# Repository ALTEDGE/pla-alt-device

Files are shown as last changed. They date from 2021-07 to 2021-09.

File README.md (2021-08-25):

# pla-alt-device

This repository contains the source code and hardware design files for the PLA ALT Avatar Motion Controller.

To compile the source code, use the [Arduino IDE](https://www.arduino.cc/en/software). After running the Arduino IDE, an `Arduino` folder is created in your Documents folder. Copy the `hardware` folder in this repo into that `Arudino` folder; then, the Arduino IDE should show "PLA ALT" as a board option.

The controller's hardware was designed using [EAGLE](https://www.autodesk.com/products/eagle/overview). Schematic and board files are located in the `eagle` folder.

## Brief user guide

The controller appears to the computer as a regular gaming joystick/controller. The [PLA ALT GUI](https://github.com/ALTEDGE/pla-alt-gui) must be running in order to use the controller to its full potential.

To reprogram the ALT controller, put it into programming mode by holding down the right joystick button while plugging into the computer; the LEDs should not turn on. After uploading new code through the IDE, reconnect the controller.

The ALT controller self-calibrates when it is first powered on. If recalibration is ever necessary, hold down the left joystick button while plugging into the computer. Release the button once the LEDs light up white. Calibration is finished once the LEDs return to blue.

### Licensing

The ALT controller's source code is licensed under the GNU GPLv3; see the LICENSE file in the top directory. The controller's hardware files (EAGLE schematic and board files) are licensed under the TAPR Open Hardware License; see the LICENSE file in the `eagle` folder.

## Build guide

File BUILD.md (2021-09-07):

# Programming the PLA ALT controller

This guide will show you how to program the PLA ALT controller with new firmware. This includes burning the PLA ALT bootloader and uploading the latest code.

To burn the bootloader, two pieces of hardware are required:

1. A USBasp programmer (available from many places, like [Amazon](https://www.amazon.com/Geekstory-Microcontroller-Programmer-Downloader-Adapter/dp/B07NZ59VK2/)).
2. A 6-pin Pogo adapter ([on Amazon](https://www.amazon.com/pin-AVR-ICSP-Pogo-Adapter/dp/B075Q25BK3/)).

This guide assumes you are running Windows 10.

## 1. Prepare the USB programmer

Plug the USB programmer into the computer. Then, download and run the program Zadig from [here](https://zadig.akeo.ie/). This program installs drivers for the programmer.

Once open, the drop-down box should contain an entry (like "USBasp"). Click "Install Driver"; once finished, exit Zadig.

## 2. Prepare the Arduino IDE

The Arduino IDE can be downloaded [here](https://www.arduino.cc/en/software). Once installed, run the Arduino IDE program. This will create a folder that we will be copying files into. Just close the IDE once it is open.

## 3. Download the PLA ALT source code

Download a .zip of the latest source code [here](https://github.com/ALTEDGE/pla-alt-device/archive/refs/heads/master.zip). Once downloaded, unzip the archive. Rename the extracted folder to `pla-device`.

Inside the `pla-device` folder is a `hardware` folder. Copy and paste the `hardware` folder into `Documents\Arduino`.

## 4. Programming the PLA ALT controller

Now, open the Arduino IDE again. From the menu bar, select **Tools > Board: > PLA: > PLA ALT**. Also select **Tools > Programmer: > USBasp**.

### a. Burning the bootloader

Plug the PLA controller into the computer, and connect the programmer to it by pressing it into the programming port on the bottom of the PLA controller (check the pin labels and make sure they line up and match):

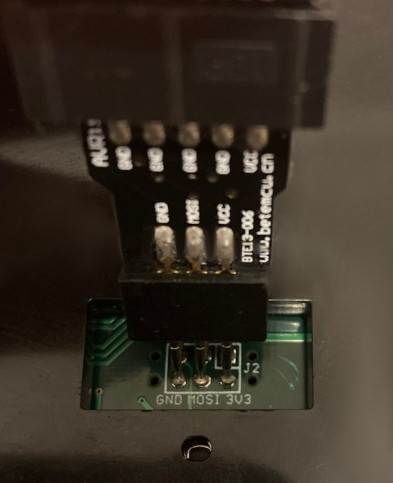
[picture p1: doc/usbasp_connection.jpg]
Programmer connection


Keep the programmer connected, and choose **Tools > Burn Bootloader** from the menu bar. Once the bootloader burning is finished, you may remove the programmer from the PLA controller.

### b. Uploading the code

Under **Tools > Port**, we need to select the COM port for the PLA controller. If there are multiple COM ports, open Device Manager (can be found by pressing Windows key + X) and look under "Ports (COM & LPT)". The PLA controller will appear as a Sparkfun Pro Micro.

Once the port is selected, simply press **Sketch > Upload**. When finished, reconnect the controller and the blue/white LEDs should light up.

## Notes

* Once the bootloader has been burned to a device, it does not need to be burned again (unless there is a new bootloader version).
* To program the PLA controller after the bootloader has been uploaded, plug the contoller into the computer **while** pressing down the right joystick. The controller's lights will not turn on if you successfully entered the programming mode.
* If an error occurs while working with the Arduino IDE, go to **File > Prefences** and next to "Show verbose output during:" check both the compilation and upload boxes. Repeat the step you were stuck on, and detailed information on what went wrong should be given.

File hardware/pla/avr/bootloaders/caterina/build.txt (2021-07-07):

make clean
make PID=0x9209 F_CPU=16000000
copy Caterina.hex Caterina-wiflyin.hex
make clean
make PID=0x9207 F_CPU=8000000
copy Caterina.hex Caterina-lilypadusb.hex
make clean
make PID=0x9205 F_CPU=16000000
copy Caterina.hex Caterina-promicro16.hex
make clean
make PID=0x9203 F_CPU=8000000
copy Caterina.hex Caterina-promicro8.hex 
make clean
make PID=0x2B74 F_CPU=16000000
copy Caterina.hex Caterina-makey.hex
make clean
make PID=0xF100 F_CPU=8000000
copy Caterina.hex Caterina-fio.hex
make clean
make PID=0x920B F_CPU=16000000
copy Caterina.hex Caterina-minibench.hex
make clean
make PID=0x0110 F_CPU=8000000
copy Caterina.hex Caterina-lilypadusbplus.hex

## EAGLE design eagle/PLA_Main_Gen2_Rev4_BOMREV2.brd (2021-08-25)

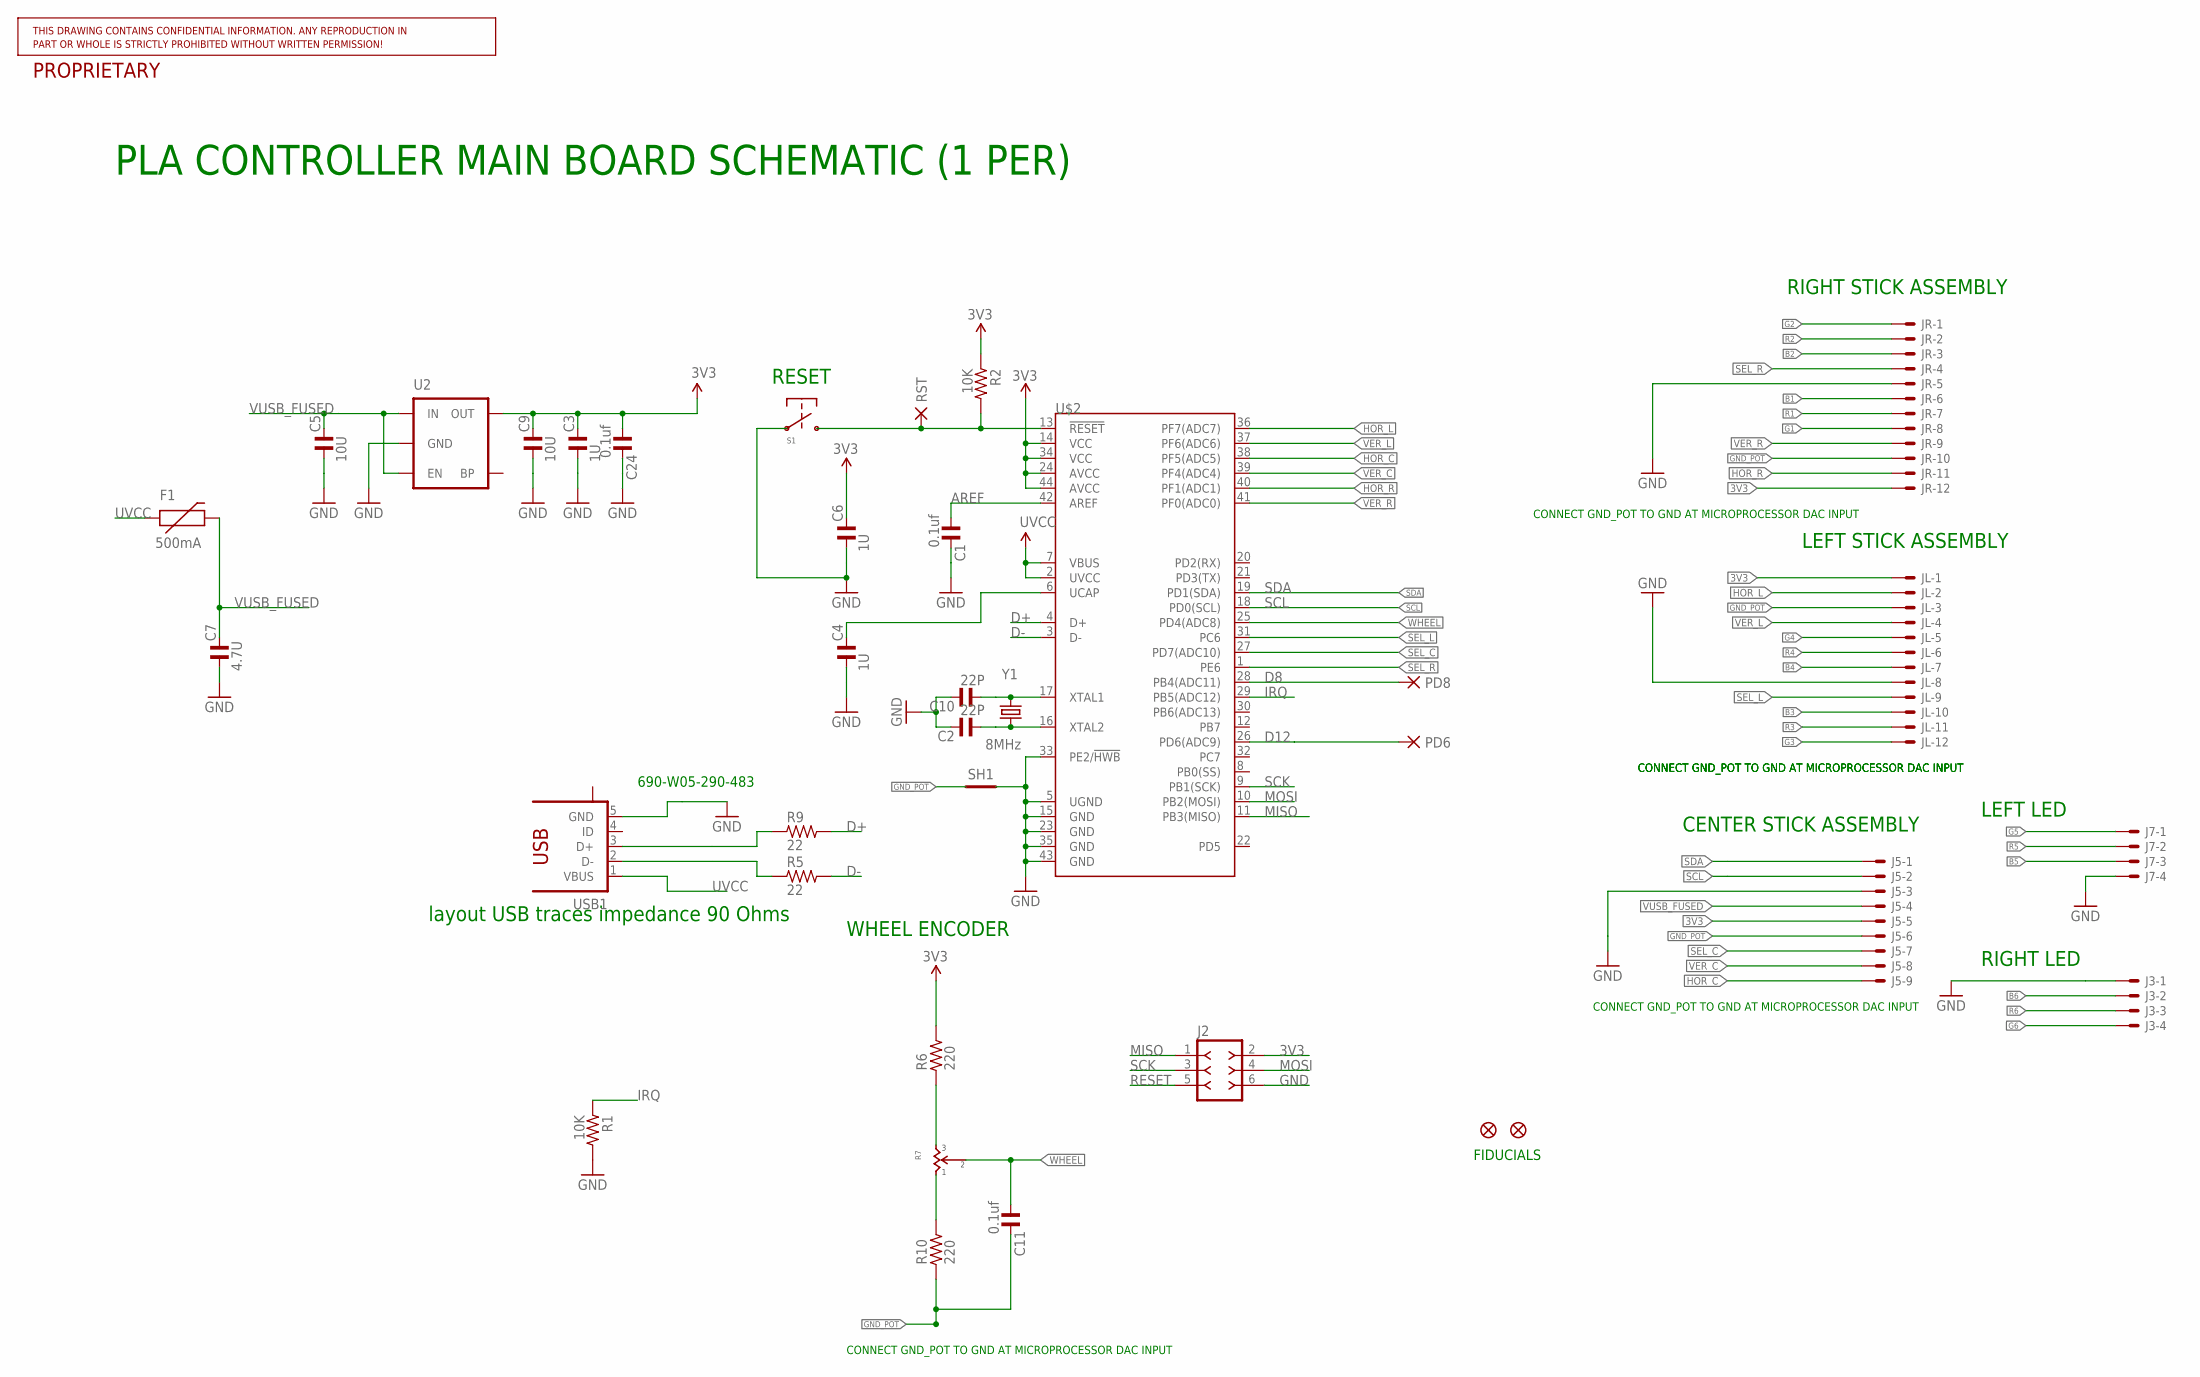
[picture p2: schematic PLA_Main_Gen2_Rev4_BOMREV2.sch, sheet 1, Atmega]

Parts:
C1, C11, C24: 0.1uf; C0603; PARTNO 64K2839
C2, C10: 22P; C0603; PARTNO 06035C220JAT2A
C3, C4, C6: 1U; C0603; PARTNO CL10B105KP8NNNC
C5, C9: 10U; C1206; PARTNO C3216X5R1H106K160AB
C7: 4.7U; C0603; PARTNO GRM188R61A475KE15D
F1: 500mA; PTC-1206; PARTNO NANOSMDH075F-02
J2: F-2X03-DIL-100; DIL-100-2X03; PARTNO *
J3, J7: SM04B-SRSS-TB; PARTNO SM04B-SRSS-TB(LF)(SN)
J5: SM09B-SRSS-TB; PARTNO SM09B-SRSS-TB
JL: SM12B-SRSS-TB; PARTNO SM12B-SRSS-TB(LF)(SN)
JP1, JP2: FIDUCIALUFIDUCIAL; MICRO-FIDUCIAL; PARTNO *
JR: SM12B-SRSS-TB; PARTNO SM12B-SRSS-TB(LF)(SN)
PD6, PD8: PAD-SMD12R; SMD12R
R1, R2: 10K; R0603; PARTNO ERJ-PA3J103V
R5, R9: 22; R0603; PARTNO ERJ-PA3J220V
R6, R10: 220; R0603; PARTNO ERJ-PA3J221V
R7: SV01A103AEA01R00; PARTNO SV01A103AEA01R00
RST: PAD-SMD10R; SMD10R
S1: KMR211GLFS; PARTNO KMR211GLFS
SH1: SHORTT5; SHORT_TOP-50; PARTNO *
U2: V_REG_LDOSMD; SOT23-5; PARTNO MIC5219-3.3YM5-TR
U$2: ATMEGA32U4QFN; QFN-44; PARTNO ATMEGA32U4-MU
USB1: 10118192-0001LF; PARTNO 10118192-0001LF
Y1: 8MHz; CRYSTAL-SMD-5X3; PARTNO ABM3B-8.000MHZ-B2-T

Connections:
3V3: C3.2, C6.2, C9.2, C24.1, J2.2, J5.5, JL.1, JR.12, R2.1, R6.2, U2.5 (OUT), U$2.14 (VCC), U$2.24 (AVCC), U$2.34 (VCC), U$2.44 (AVCC); also elsewhere on the board
AREF: C1.1, U$2.42 (AREF)
B1: JR.6; also elsewhere on the board
B2: JR.3; also elsewhere on the board
B3: JL.10; also elsewhere on the board
B4: JL.7; also elsewhere on the board
B5: J7.3; also elsewhere on the board
B6: J3.2; also elsewhere on the board
D8: PD8.PAD, U$2.28 (PB4(ADC11))
D12: PD6.PAD, U$2.26 (PD6(ADC9))
D+: R9.2, U$2.4 (D+)
D-: R5.2, U$2.3 (D-)
G1: JR.8; also elsewhere on the board
G2: JR.1; also elsewhere on the board
G3: JL.12; also elsewhere on the board
G4: JL.5; also elsewhere on the board
G5: J7.1; also elsewhere on the board
G6: J3.4; also elsewhere on the board
GND: C1.2, C2.2, C3.1, C4.1, C5.1, C6.1, C7.1, C9.1, C10.2, C24.2, J2.6, J3.1, J5.3, J7.4, JL.8, JR.5, R1.2, S1.1A (1), S1.1B (1), SH1.2, U2.2 (GND), U$2.5 (UGND), U$2.15 (GND), U$2.23 (GND), U$2.33 (PE2/!HWB), U$2.35 (GND), U$2.43 (GND), USB1.5 (GND); also elsewhere on the board
GND_POT: C11.2, J5.6, JL.3, JR.10, R10.1, SH1.1
HOR_C: J5.9, U$2.38 (PF5(ADC5))
HOR_L: JL.2, U$2.36 (PF7(ADC7))
HOR_R: JR.11, U$2.40 (PF1(ADC1))
IRQ: R1.1, U$2.29 (PB5(ADC12))
MISO: J2.1, U$2.11 (PB3(MISO))
MOSI: J2.4, U$2.10 (PB2(MOSI))
unnamed: C2.1, U$2.16 (XTAL2), Y1.1
unnamed: C10.1, U$2.17 (XTAL1), Y1.3 (2)
unnamed: C4.2, U$2.6 (UCAP)
unnamed: R6.1, R7.3
unnamed: R7.1, R10.2
R1: JR.7; also elsewhere on the board
R2: JR.2; also elsewhere on the board
R3: JL.11; also elsewhere on the board
R4: JL.6; also elsewhere on the board
R5: J7.2; also elsewhere on the board
R6: J3.3; also elsewhere on the board
RESET: J2.5, R2.2, RST.PAD, S1.2A (2), S1.2B (2), U$2.13 (!RESET)
SCK: J2.3, U$2.9 (PB1(SCK))
SCL: J5.2, U$2.18 (PD0(SCL)); also elsewhere on the board
SDA: J5.1, U$2.19 (PD1(SDA)); also elsewhere on the board
SEL_C: J5.7, U$2.27 (PD7(ADC10))
SEL_L: JL.9, U$2.31 (PC6)
SEL_R: JR.4, U$2.1 (PE6)
USB_N: R5.1, USB1.2 (D-)
USB_P: R9.1, USB1.3 (D+)
UVCC: F1.1, U$2.2 (UVCC), U$2.7 (VBUS), USB1.1 (VBUS)
VER_C: J5.8, U$2.39 (PF4(ADC4))
VER_L: JL.4, U$2.37 (PF6(ADC6))
VER_R: JR.9, U$2.41 (PF0(ADC0))
VUSB_FUSED: C5.2, C7.2, F1.2, J5.4, U2.1 (IN), U2.3 (EN); also elsewhere on the board
WHEEL: C11.1, R7.2, R7.2A (2), U$2.25 (PD4(ADC8))

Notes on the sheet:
690-W05-290-483
layout USB traces impedance 90 Ohms
LEFT STICK ASSEMBLY
CONNECT GND_POT TO GND AT MICROPROCESSOR DAC INPUT
RIGHT STICK ASSEMBLY
CENTER STICK ASSEMBLY
WHEEL ENCODER
RESET
LEFT LED
RIGHT LED
FIDUCIALS
PLA CONTROLLER MAIN BOARD SCHEMATIC (1 PER)

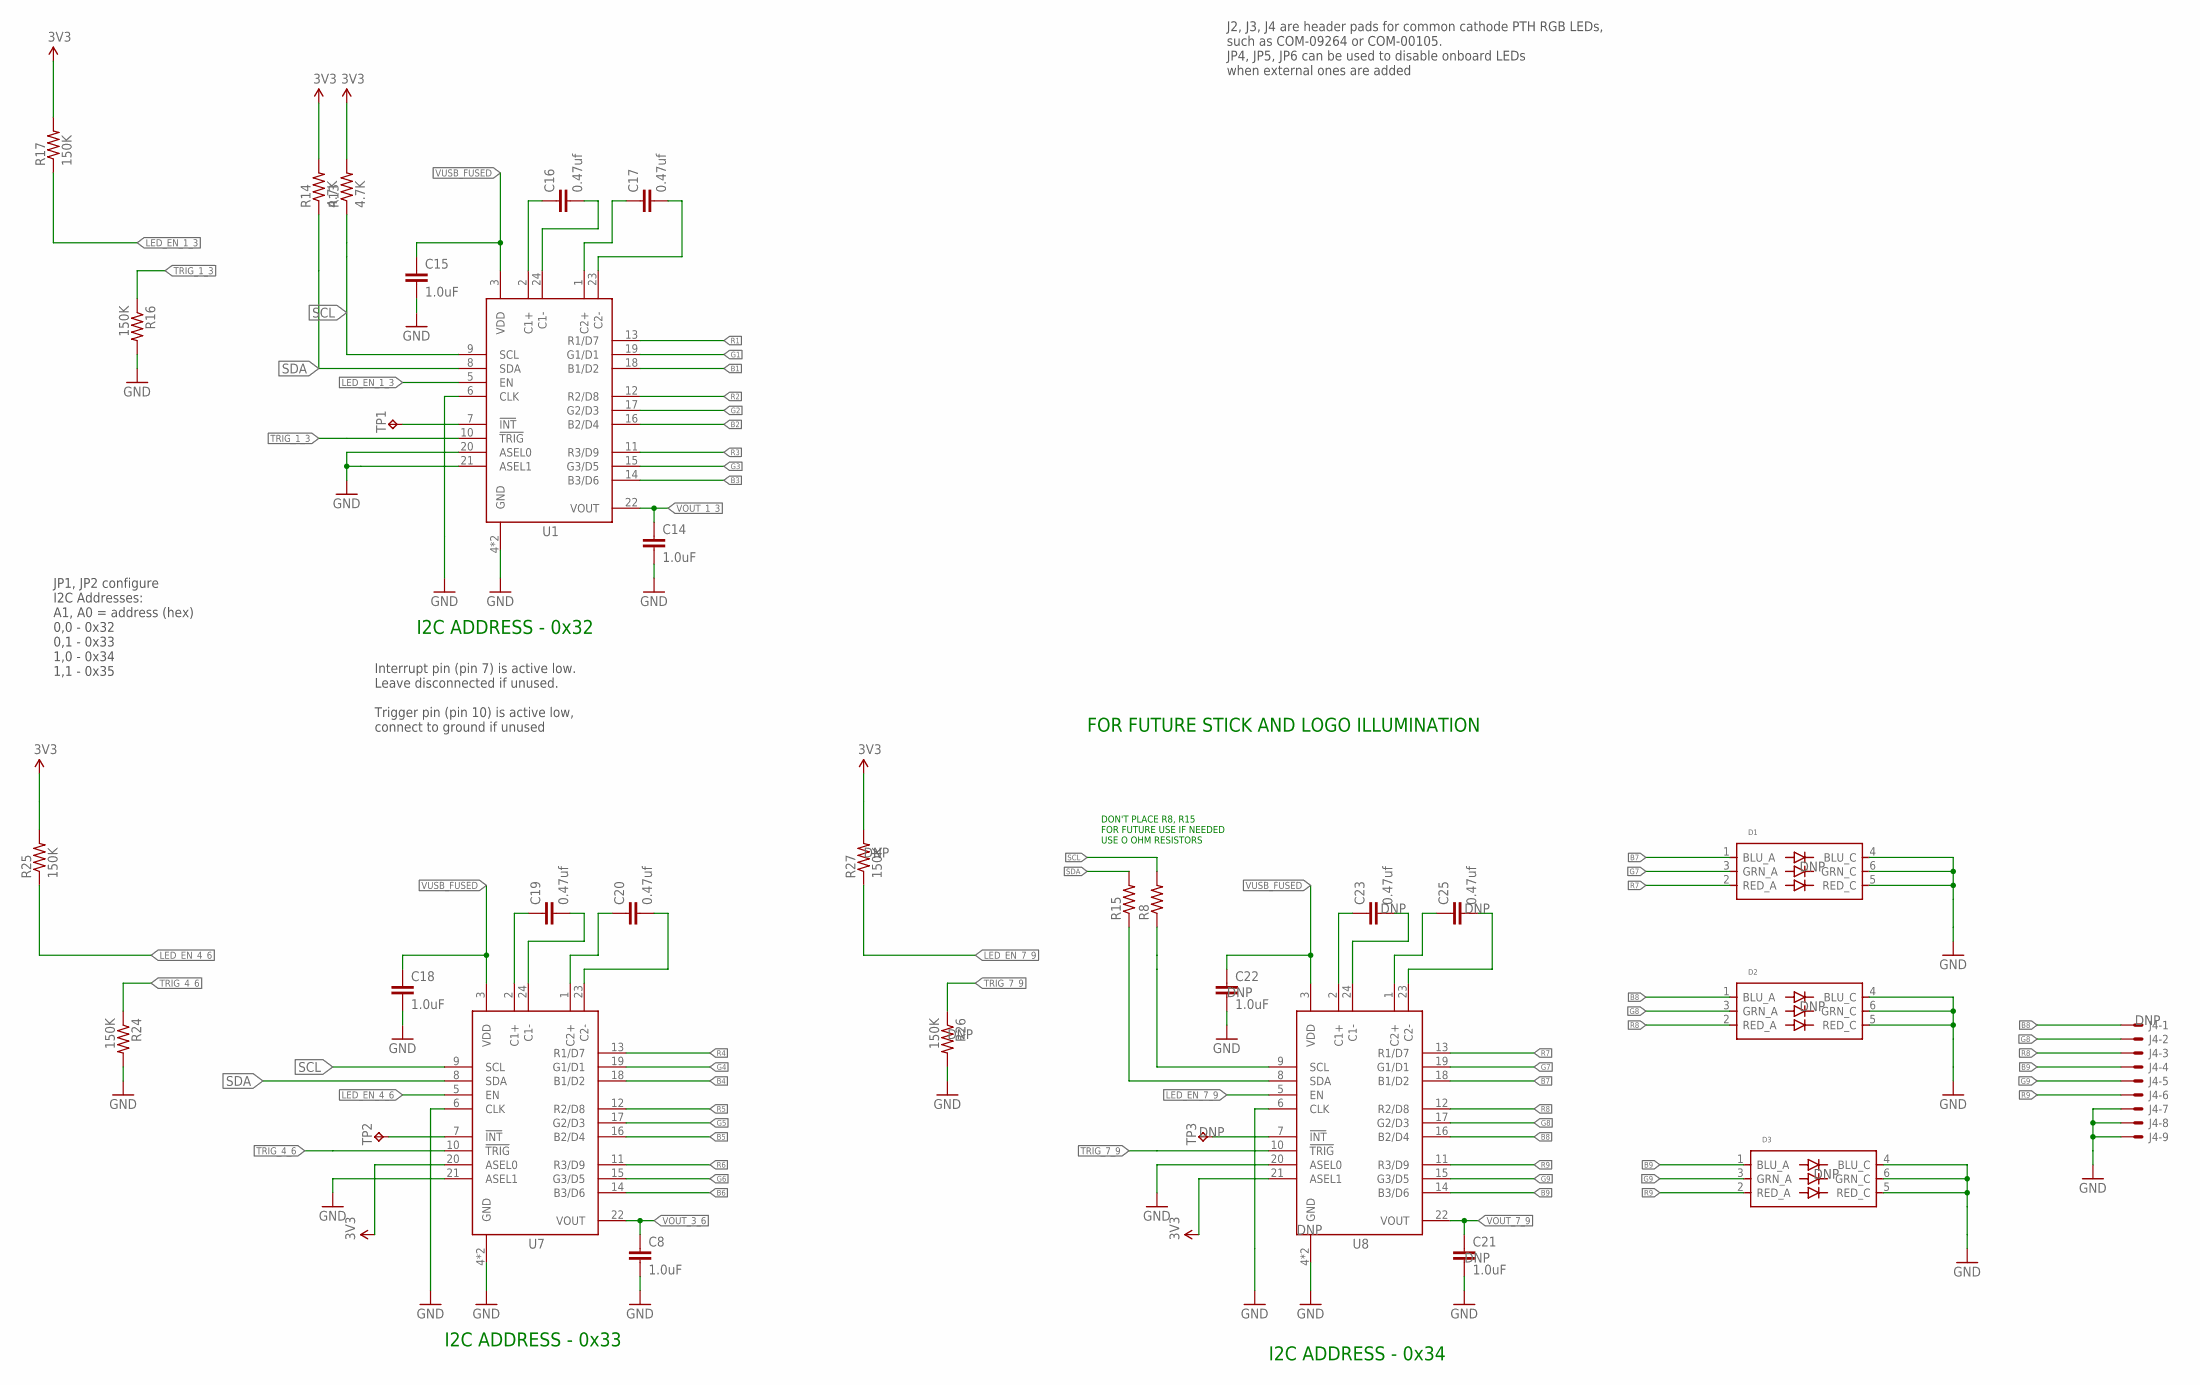
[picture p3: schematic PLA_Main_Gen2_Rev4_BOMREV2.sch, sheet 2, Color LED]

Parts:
C8, C14, C15, C18, C21, C22: 1.0uF; 0603-CAP; PARTNO CL10B105KP8NNNC
C16, C17, C19, C20, C23, C25: 0.47uf; 0603-CAP; PARTNO 0603YG474ZAT2A
D1, D2, D3: XZFBBM2ACRDG92W-3; PARTNO XZFBBM2ACRDG92W-3
J4: BM09B-SRSS-TB; PARTNO BM09B-SRSS-TB
R8, R15: 4.7KOHM-1/10W-1%(0603); 0603-RES; PARTNO ERJ-PA3J472V
R13, R14: 4.7K; 0603-RES; PARTNO ERJ-PA3J472V
R16, R17, R24, R25, R26, R27: 150K; 0603-RES; PARTNO ERJ-PA3J154V
TP1, TP2, TP3: TP-040; PARTNO *
U1, U7, U8: LP55231WQFN; WQFN-24; PARTNO LP55231SQX/NOPB

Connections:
3V3: R13.2, R14.2, R17.2, R25.2, R27.2, U7.20 (ASEL0), U8.21 (ASEL1); also elsewhere on the board
B1: U1.18 (B1/D2); also elsewhere on the board
B2: U1.16 (B2/D4); also elsewhere on the board
B3: U1.14 (B3/D6); also elsewhere on the board
B4: U7.18 (B1/D2); also elsewhere on the board
B5: U7.16 (B2/D4); also elsewhere on the board
B6: U7.14 (B3/D6); also elsewhere on the board
B7: D1.1 (BLU_A), U8.18 (B1/D2)
B8: D2.1 (BLU_A), J4.1, U8.16 (B2/D4)
B9: D3.1 (BLU_A), J4.4, U8.14 (B3/D6)
G1: U1.19 (G1/D1); also elsewhere on the board
G2: U1.17 (G2/D3); also elsewhere on the board
G3: U1.15 (G3/D5); also elsewhere on the board
G4: U7.19 (G1/D1); also elsewhere on the board
G5: U7.17 (G2/D3); also elsewhere on the board
G6: U7.15 (G3/D5); also elsewhere on the board
G7: D1.3 (GRN_A), U8.19 (G1/D1)
G8: D2.3 (GRN_A), J4.2, U8.17 (G2/D3)
G9: D3.3 (GRN_A), J4.5, U8.15 (G3/D5)
GND: C8.2, C14.2, C15.2, C18.2, C21.2, C22.2, D1.4 (BLU_C), D1.5 (RED_C), D1.6 (GRN_C), D2.4 (BLU_C), D2.5 (RED_C), D2.6 (GRN_C), D3.4 (BLU_C), D3.5 (RED_C), D3.6 (GRN_C), J4.7, J4.8, J4.9, R16.2, R24.2, R26.2, U1.4 (GND), U1.6 (CLK), U1.20 (ASEL0), U1.21 (ASEL1), U1.EP (GND), U7.4 (GND), U7.6 (CLK), U7.21 (ASEL1), U7.EP (GND), U8.4 (GND), U8.6 (CLK), U8.20 (ASEL0), U8.EP (GND); also elsewhere on the board
LED_EN_1_3: R17.1, U1.5 (EN)
LED_EN_4_6: R25.1, U7.5 (EN)
LED_EN_7_9: R27.1, U8.5 (EN)
unnamed: TP1.1, U1.7 (!INT)
unnamed: C19.1, U7.2 (C1+)
unnamed: C19.2, U7.24 (C1-)
unnamed: C16.1, U1.2 (C1+)
unnamed: C16.2, U1.24 (C1-)
unnamed: C17.1, U1.1 (C2+)
unnamed: C17.2, U1.23 (C2-)
unnamed: C20.1, U7.1 (C2+)
unnamed: C20.2, U7.23 (C2-)
unnamed: TP2.1, U7.7 (!INT)
unnamed: C23.1, U8.2 (C1+)
unnamed: C23.2, U8.24 (C1-)
unnamed: C25.1, U8.1 (C2+)
unnamed: C25.2, U8.23 (C2-)
unnamed: TP3.1, U8.7 (!INT)
R1: U1.13 (R1/D7); also elsewhere on the board
R2: U1.12 (R2/D8); also elsewhere on the board
R3: U1.11 (R3/D9); also elsewhere on the board
R4: U7.13 (R1/D7); also elsewhere on the board
R5: U7.12 (R2/D8); also elsewhere on the board
R6: U7.11 (R3/D9); also elsewhere on the board
R7: D1.2 (RED_A), U8.13 (R1/D7)
R8: D2.2 (RED_A), J4.3, U8.12 (R2/D8)
R9: D3.2 (RED_A), J4.6, U8.11 (R3/D9)
SCL: R8.2, R13.1, U1.9 (SCL), U7.9 (SCL); also elsewhere on the board
SCL2: R8.1, U8.9 (SCL)
SDA: R14.1, R15.2, U1.8 (SDA), U7.8 (SDA); also elsewhere on the board
SDA2: R15.1, U8.8 (SDA)
TRIG_1_3: R16.1, U1.10 (!TRIG)
TRIG_4_6: R24.1, U7.10 (!TRIG)
TRIG_7_9: R26.1, U8.10 (!TRIG)
VOUT_1_3: C14.1, U1.22 (VOUT)
VOUT_3_6: C8.1, U7.22 (VOUT)
VOUT_7_9: C21.1, U8.22 (VOUT)
VUSB_FUSED: C15.1, C18.1, C22.1, U1.3 (VDD), U7.3 (VDD), U8.3 (VDD); also elsewhere on the board

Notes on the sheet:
JP1, JP2 configure I2C Addresses: A1, A0 = address (hex) 0,0 - 0x32 0,1 - 0x33 1,0 - 0x34 1,1 - 0x35
J2, J3, J4 are header pads for common cathode PTH RGB LEDs, such as COM-09264 or COM-00105. JP4, JP5, JP6 can be used to disable onboard LEDs when external ones are added
Interrupt pin (pin 7) is active low. Leave disconnected if unused. Trigger pin (pin 10) is active low, connect to ground if unused
FOR FUTURE STICK AND LOGO ILLUMINATION
I2C ADDRESS - 0x32
I2C ADDRESS - 0x33
I2C ADDRESS - 0x34
DON'T PLACE R8, R15 FOR FUTURE USE IF NEEDED USE O OHM RESISTORS

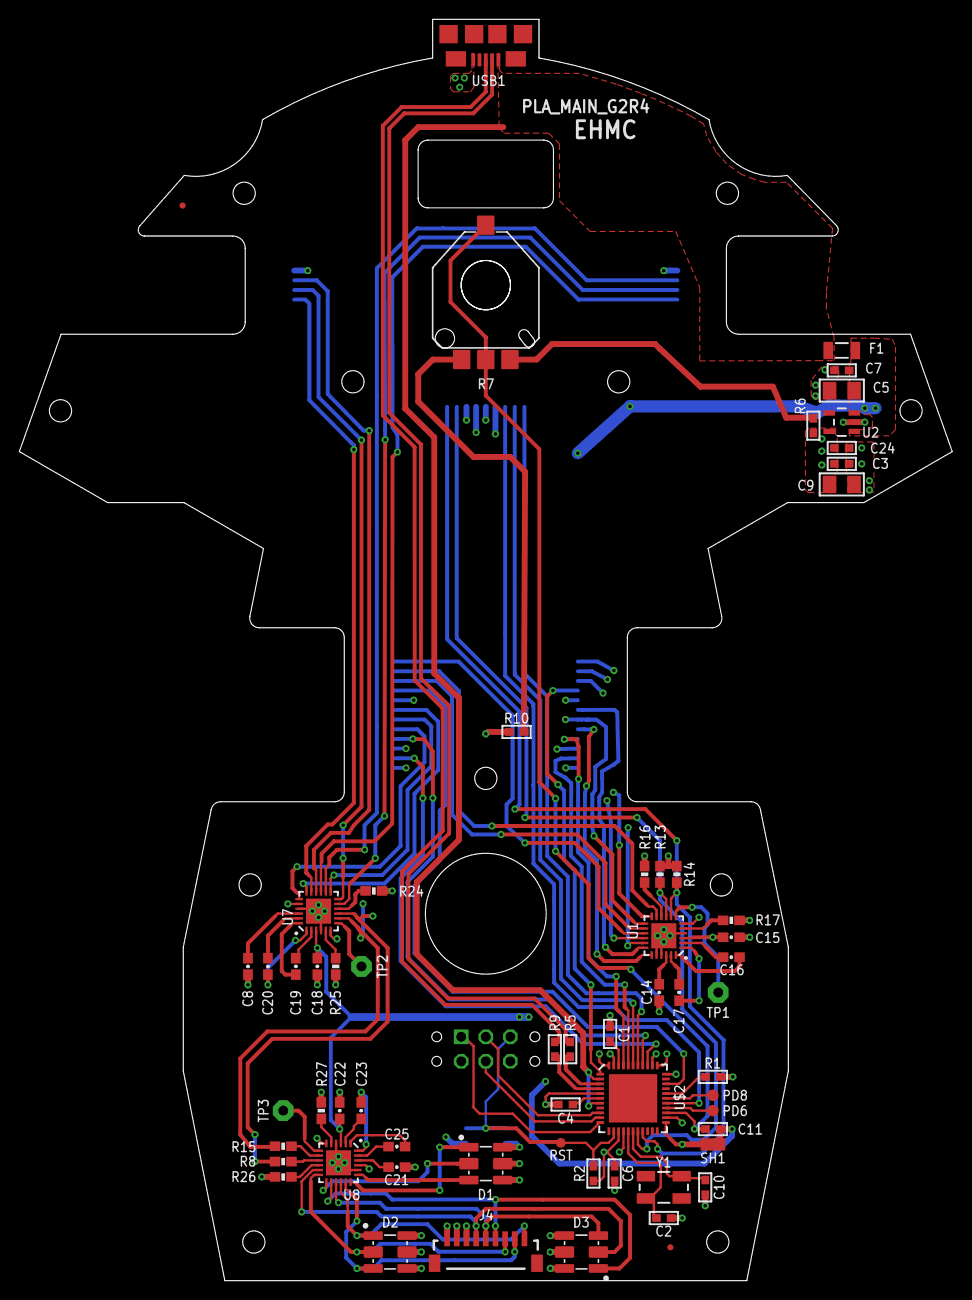
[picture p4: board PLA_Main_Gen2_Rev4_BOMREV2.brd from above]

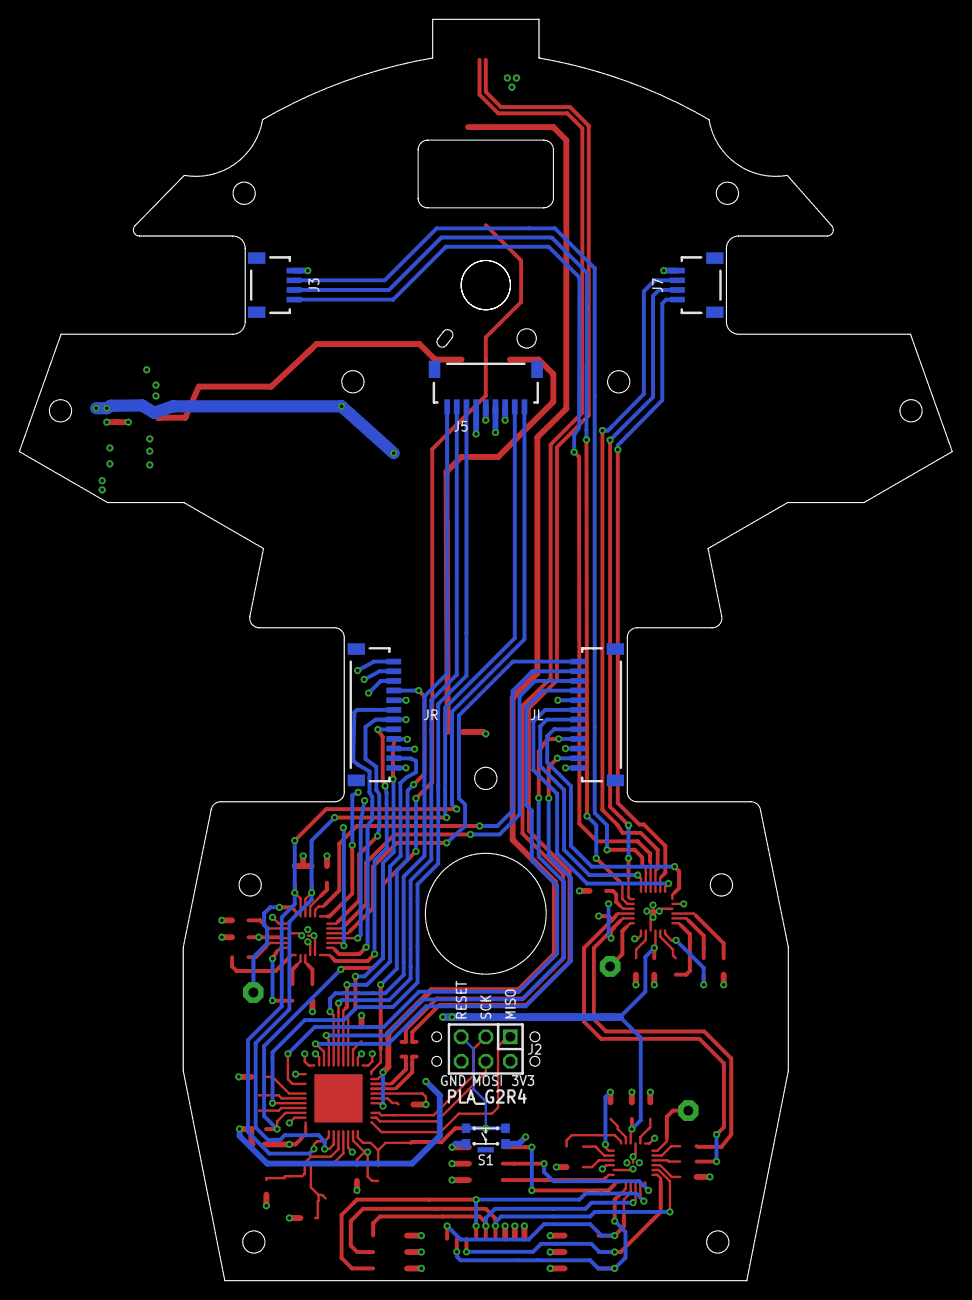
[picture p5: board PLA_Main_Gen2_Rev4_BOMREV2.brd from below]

Board: 4 copper layers, 96.5 x 130.5 mm, 70 parts (7 on the bottom side), 87 nets.

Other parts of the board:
U$3: FAB_FRAME_ANSI-A
U$4: FAB_DOCFIELD_GENERIC

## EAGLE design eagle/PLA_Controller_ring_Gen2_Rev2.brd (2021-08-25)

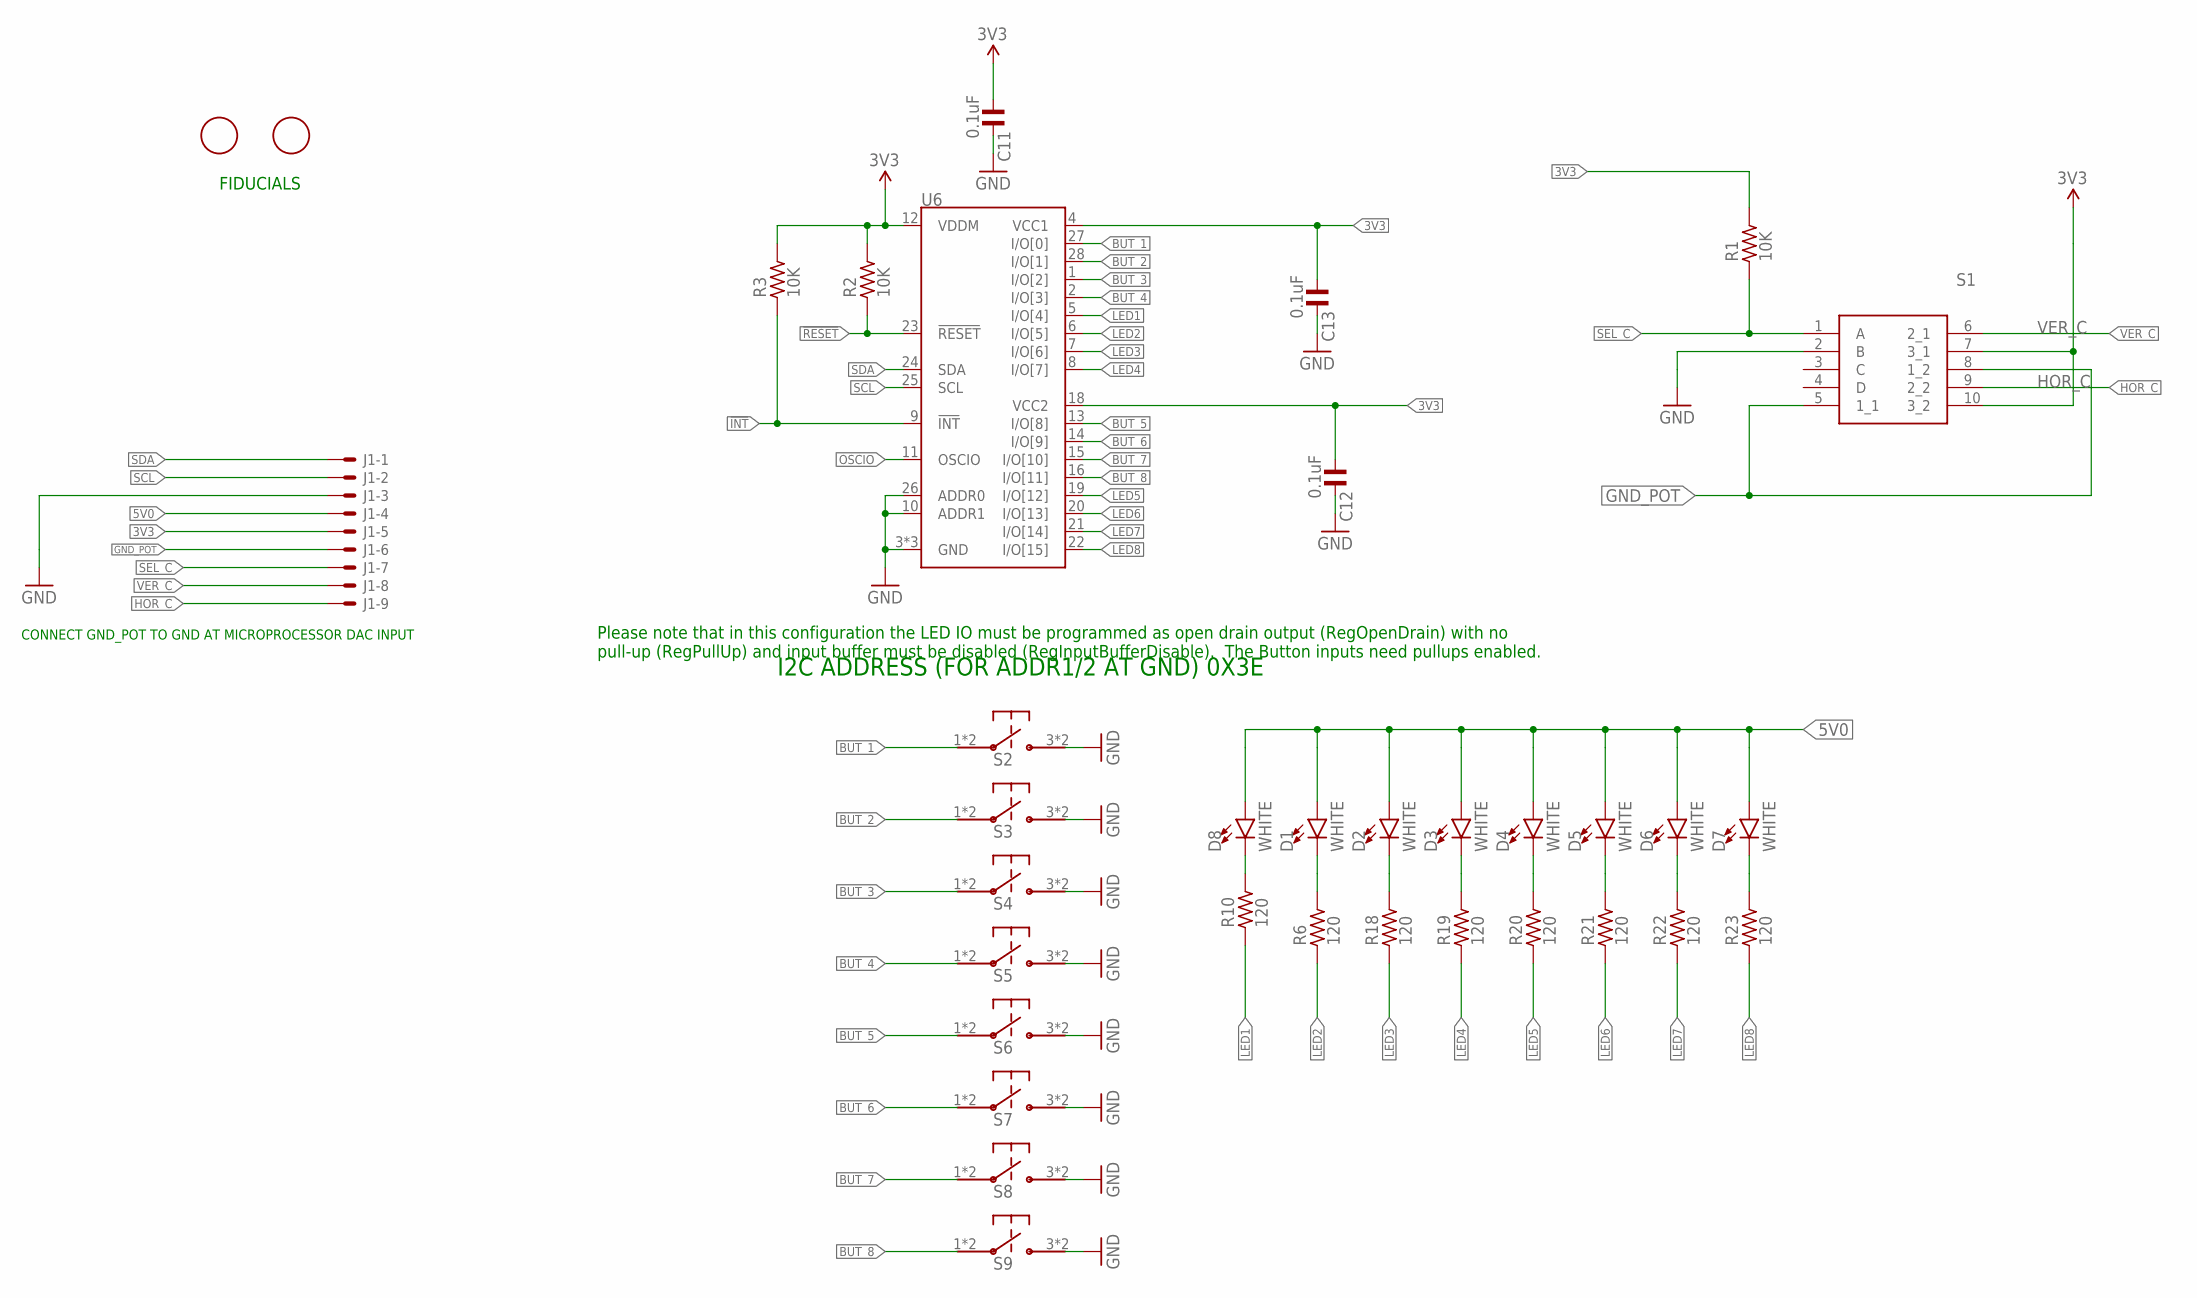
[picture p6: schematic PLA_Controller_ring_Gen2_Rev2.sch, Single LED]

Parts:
C11, C12, C13: 0.1uF; C0603; PARTNO CAP-00810
D1, D2, D3, D4, D5, D6, D7, D8: WHITE; LED-0603; PARTNO QBLP601-IW
J1: BM09B-SRSS-TB; PARTNO BM09B-SRSS-TB
R1, R2, R3: 10K; R0603; PARTNO ERJ-2GEJ103X
R6, R10, R18, R19, R20, R21, R22, R23: 120; R0603; PARTNO ERJ-PA3J121V
S1: RKJXV1224005; PARTNO RKJXV1224005
S2, S3, S4, S5, S6, S7, S8, S9: TL3315NF100Q; PARTNO TL3315NF100Q
U6: SX1509; QFN-28; PARTNO SX1509BIULTRT
U$8, U$9: FIDUCIAL; FIDUCIAL_1MM; PARTNO *

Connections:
3V3: C11.1, C12.1, C13.1, J1.5, R1.2, R2.2, R3.2, S1.7 (3_1), S1.10 (3_2), U6.4 (VCC1), U6.12 (VDDM), U6.18 (VCC2)
5V0: D1.A, D2.A, D3.A, D4.A, D5.A, D6.A, D7.A, D8.A, J1.4
!INT: R3.1, U6.9 (!INT)
!RESET: R2.1, U6.23 (!RESET)
BUT_1: S2.1, S2.2, U6.27 (I/O[0])
BUT_2: S3.1, S3.2, U6.28 (I/O[1])
BUT_3: S4.1, S4.2, U6.1 (I/O[2])
BUT_4: S5.1, S5.2, U6.2 (I/O[3])
BUT_5: S6.1, S6.2, U6.13 (I/O[8])
BUT_6: S7.1, S7.2, U6.14 (I/O[9])
BUT_7: S8.1, S8.2, U6.15 (I/O[10])
BUT_8: S9.1, S9.2, U6.16 (I/O[11])
GND: C11.2, C12.2, C13.2, J1.3, S1.2 (B), S2.3, S2.4, S3.3, S3.4, S4.3, S4.4, S5.3, S5.4, S6.3, S6.4, S7.3, S7.4, S8.3, S8.4, S9.3, S9.4, U6.3 (GND), U6.10 (ADDR1), U6.17 (GND), U6.26 (ADDR0), U6.29 (GND)
GND_POT: J1.6, S1.5 (1_1), S1.8 (1_2)
HOR_C: J1.9, S1.9 (2_2)
LED1: R10.1, U6.5 (I/O[4])
LED2: R6.1, U6.6 (I/O[5])
LED3: R18.1, U6.7 (I/O[6])
LED4: R19.1, U6.8 (I/O[7])
LED5: R20.1, U6.19 (I/O[12])
LED6: R21.1, U6.20 (I/O[13])
LED7: R22.1, U6.21 (I/O[14])
LED8: R23.1, U6.22 (I/O[15])
unnamed: D1.C, R6.2
unnamed: D8.C, R10.2
unnamed: D2.C, R18.2
unnamed: D3.C, R19.2
unnamed: D4.C, R20.2
unnamed: D5.C, R21.2
unnamed: D6.C, R22.2
unnamed: D7.C, R23.2
OSCIO: U6.11 (OSCIO)
SCL: J1.2, U6.25 (SCL)
SDA: J1.1, U6.24 (SDA)
SEL_C: J1.7, R1.1, S1.1 (A)
VER_C: J1.8, S1.6 (2_1)

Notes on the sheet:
Please note that in this configuration the LED IO must be programmed as open drain output (RegOpenDrain) with no pull-up (RegPullUp) and input buffer must be disabled (RegInputBufferDisable). The Button inputs need pullups enabled.
CONNECT GND_POT TO GND AT MICROPROCESSOR DAC INPUT
I2C ADDRESS (FOR ADDR1/2 AT GND) 0X3E
FIDUCIALS

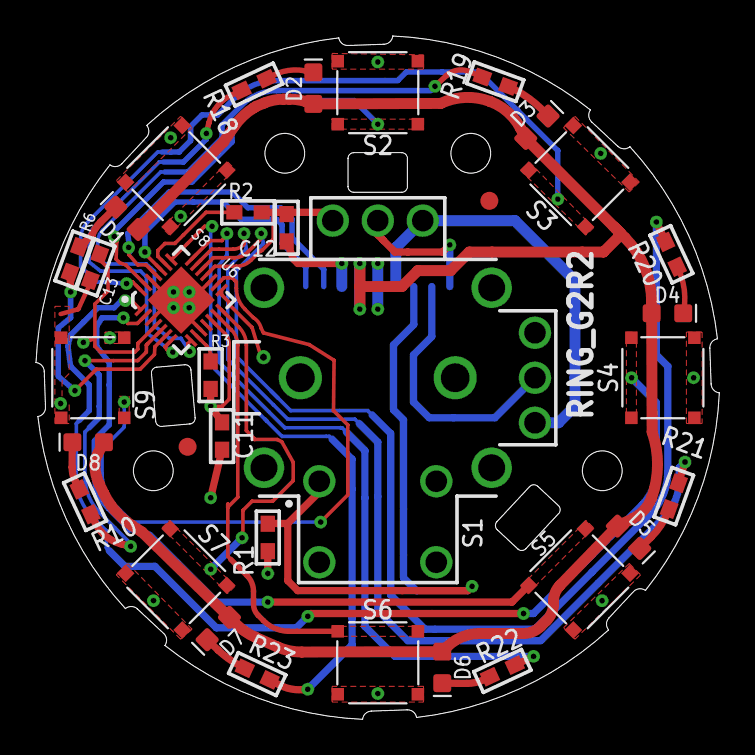
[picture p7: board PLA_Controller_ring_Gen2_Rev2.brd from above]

Board: 4 copper layers, 38.0 x 38.0 mm, 41 parts (1 on the bottom side), 35 nets.

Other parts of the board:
U$2, U$5, U$6, U$7: 086
U$3: FAB_FRAME_ANSI-A
U$4: FAB_DOCFIELD_GENERIC

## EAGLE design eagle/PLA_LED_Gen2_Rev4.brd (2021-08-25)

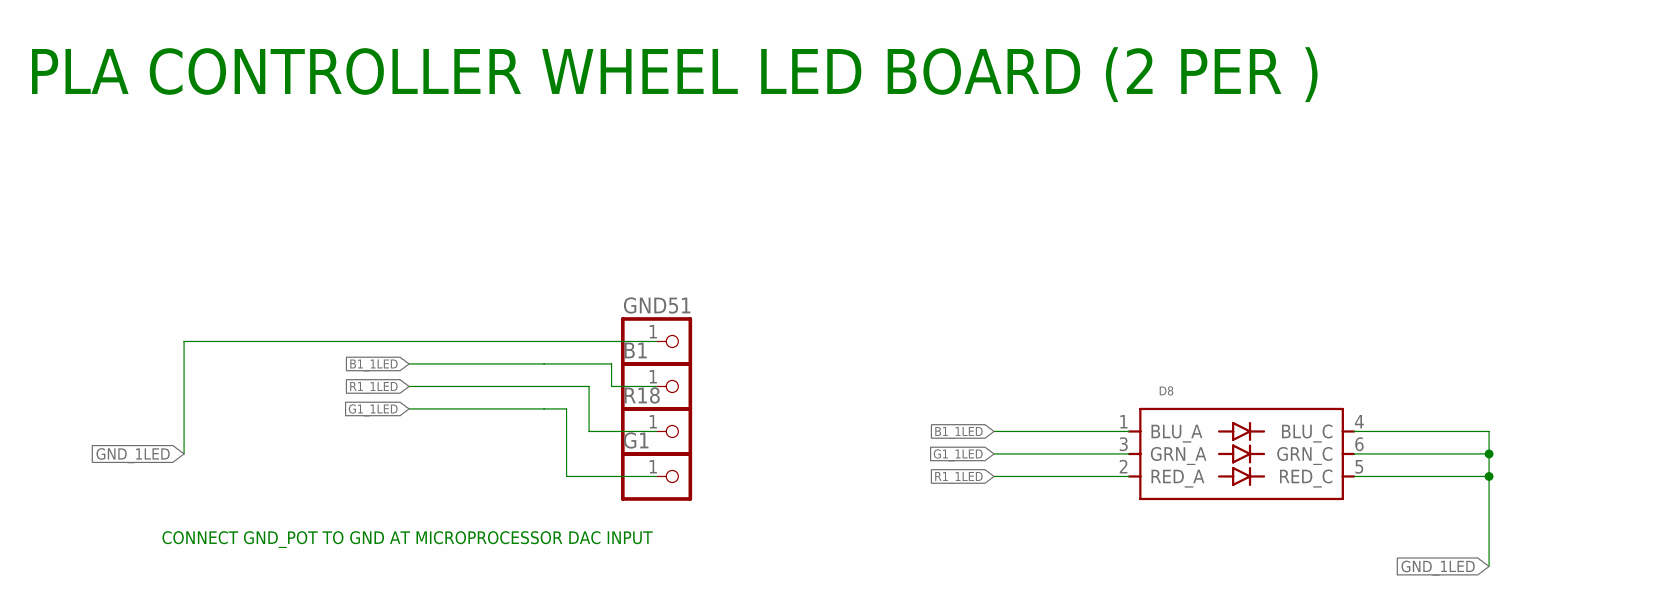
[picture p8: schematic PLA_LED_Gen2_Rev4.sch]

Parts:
B1: PINHD-1X1; 1X01; PARTNO *
D8: XZFBBM2ACRDG92W-3; PARTNO XZFBBM2ACRDG92W-3
G1: PINHD-1X1; 1X01; PARTNO *
GND51: PINHD-1X1; 1X01; PARTNO *
R18: PINHD-1X1; 1X01; PARTNO *

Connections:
B1_1LED: B1.1, D8.1 (BLU_A)
G1_1LED: D8.3 (GRN_A), G1.1
GND_1LED: D8.4 (BLU_C), D8.5 (RED_C), D8.6 (GRN_C), GND51.1
R1_1LED: D8.2 (RED_A), R18.1

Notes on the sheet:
CONNECT GND_POT TO GND AT MICROPROCESSOR DAC INPUT
PLA CONTROLLER WHEEL LED BOARD (2 PER )

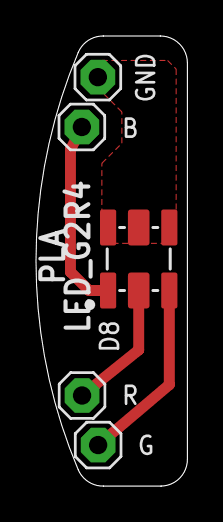
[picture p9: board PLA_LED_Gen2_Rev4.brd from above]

Board: 4 copper layers, 8.4 x 25.0 mm, 7 parts (0 on the bottom side), 4 nets.

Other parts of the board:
U$3: FAB_FRAME_ANSI-A
U$4: FAB_DOCFIELD_GENERIC

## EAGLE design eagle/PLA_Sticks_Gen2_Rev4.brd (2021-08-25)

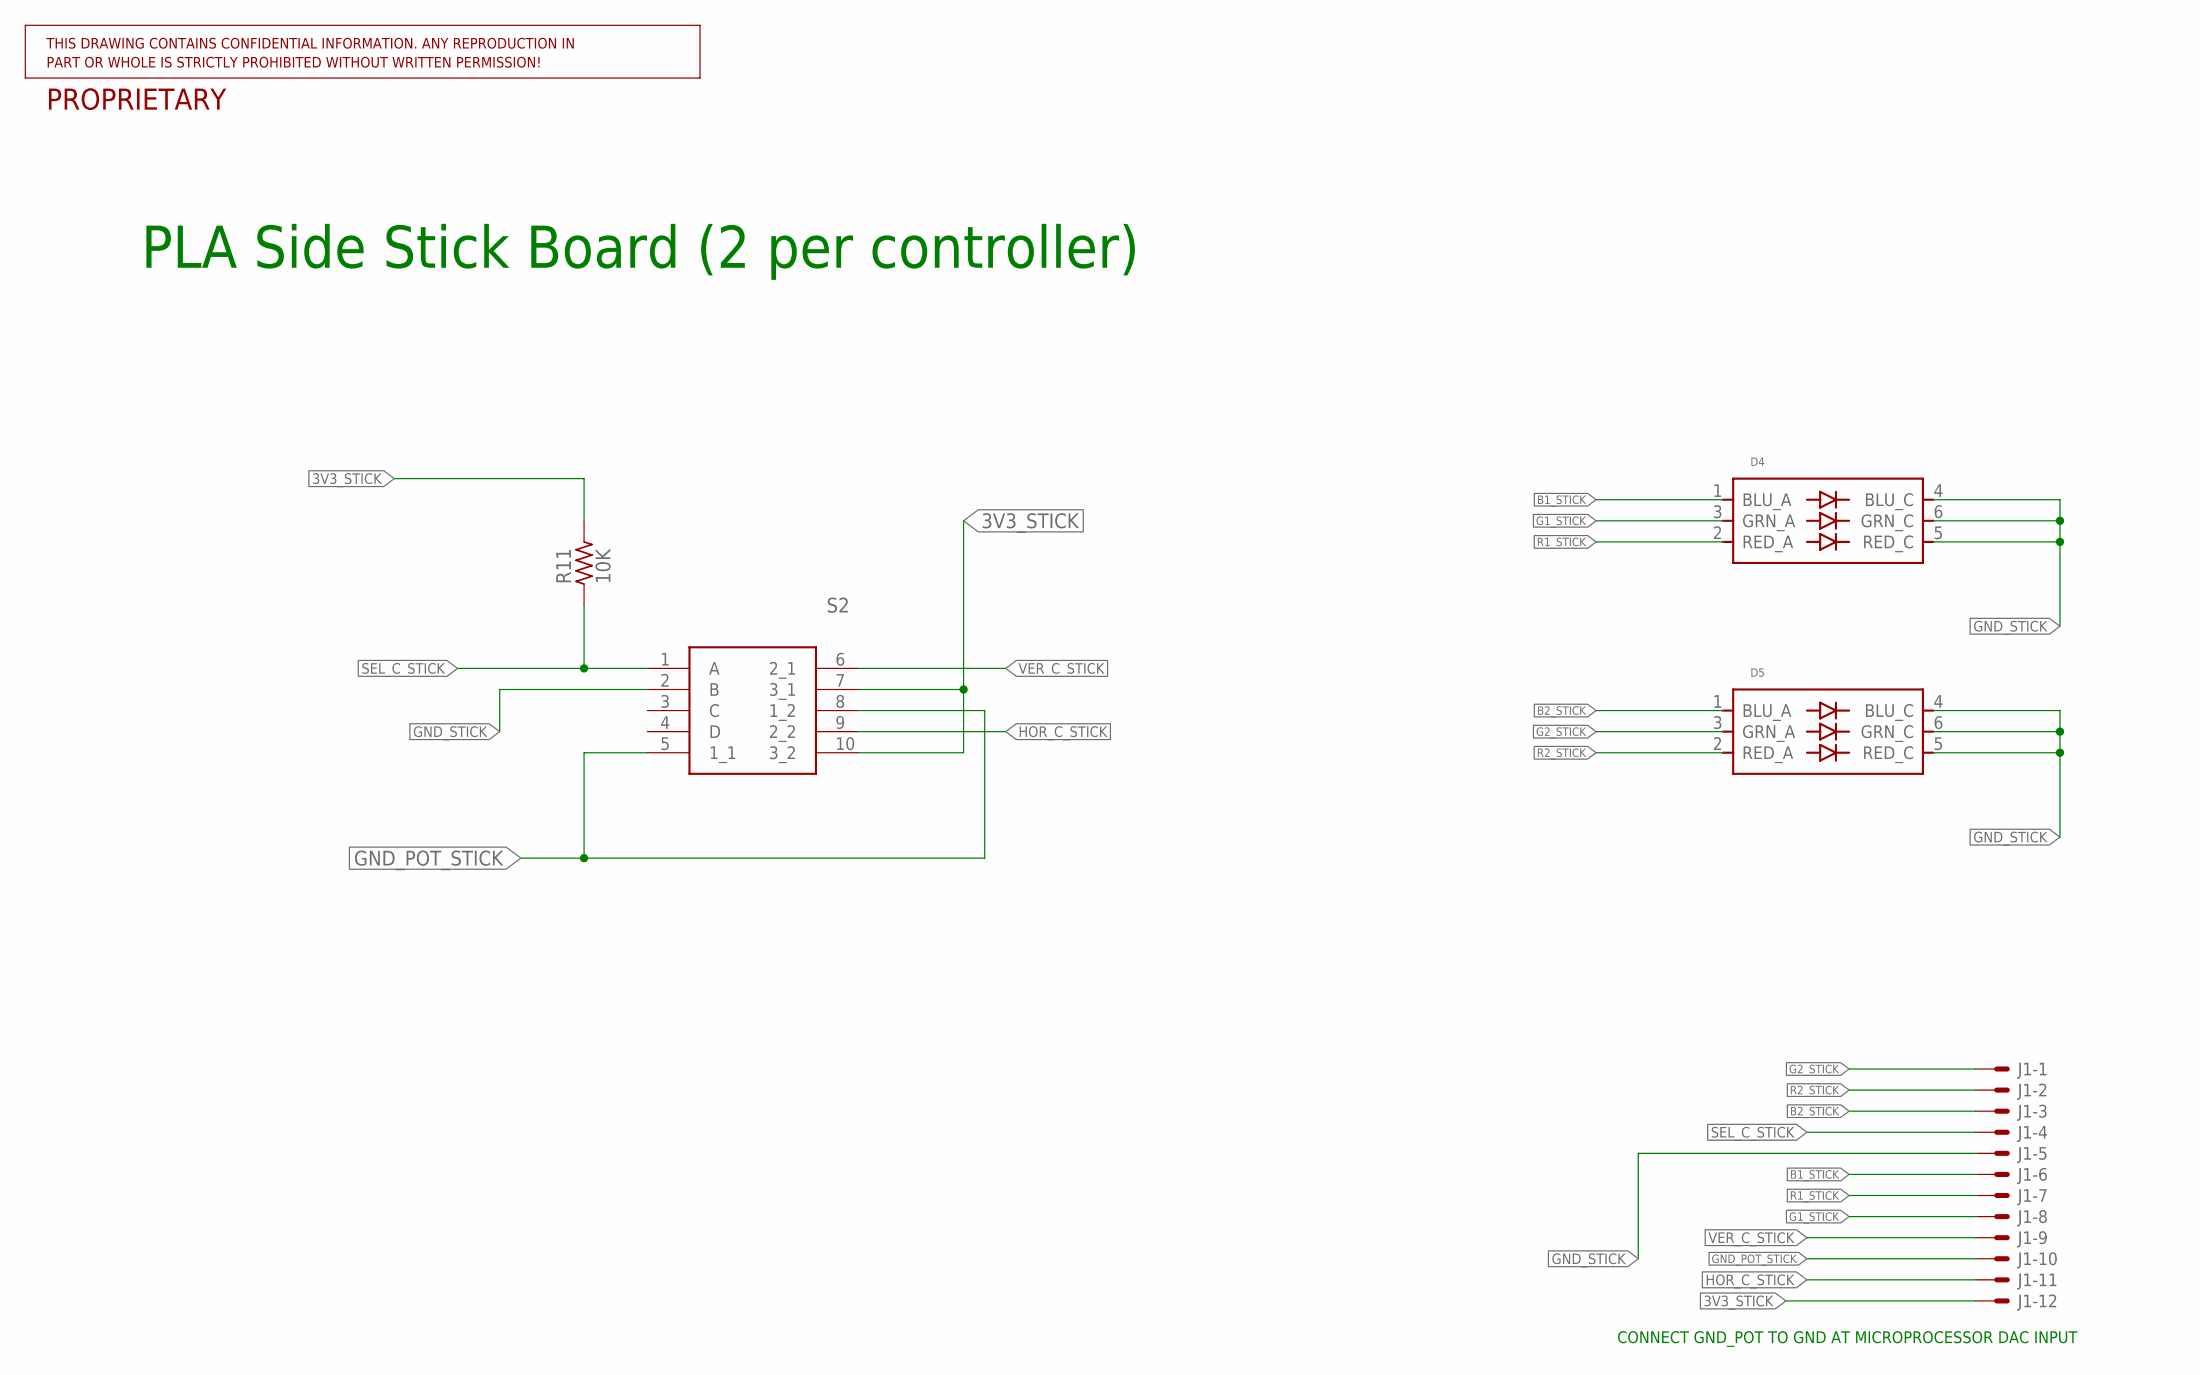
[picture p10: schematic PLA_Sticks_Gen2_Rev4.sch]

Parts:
D4, D5: XZFBBM2ACRDG92W-3; PARTNO XZFBBM2ACRDG92W-3
J1: SM12B-SSR-H-TB; PARTNO BM12B-SRSS-TB(LF)(SN)
R11: 10K; R0603; PARTNO ERJ-2GEJ103X
S2: RKJXV1224005; PARTNO RKJXV1224005

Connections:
3V3_STICK: J1.12, R11.2, S2.7 (3_1), S2.10 (3_2)
B1_STICK: D4.1 (BLU_A), J1.6
B2_STICK: D5.1 (BLU_A), J1.3
G1_STICK: D4.3 (GRN_A), J1.8
G2_STICK: D5.3 (GRN_A), J1.1
GND_POT_STICK: J1.10, S2.5 (1_1), S2.8 (1_2)
GND_STICK: D4.4 (BLU_C), D4.5 (RED_C), D4.6 (GRN_C), D5.4 (BLU_C), D5.5 (RED_C), D5.6 (GRN_C), J1.5, S2.2 (B)
HOR_C_STICK: J1.11, S2.9 (2_2)
R1_STICK: D4.2 (RED_A), J1.7
R2_STICK: D5.2 (RED_A), J1.2
SEL_C_STICK: J1.4, R11.1, S2.1 (A)
VER_C_STICK: J1.9, S2.6 (2_1)

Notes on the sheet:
CONNECT GND_POT TO GND AT MICROPROCESSOR DAC INPUT
PLA Side Stick Board (2 per controller)

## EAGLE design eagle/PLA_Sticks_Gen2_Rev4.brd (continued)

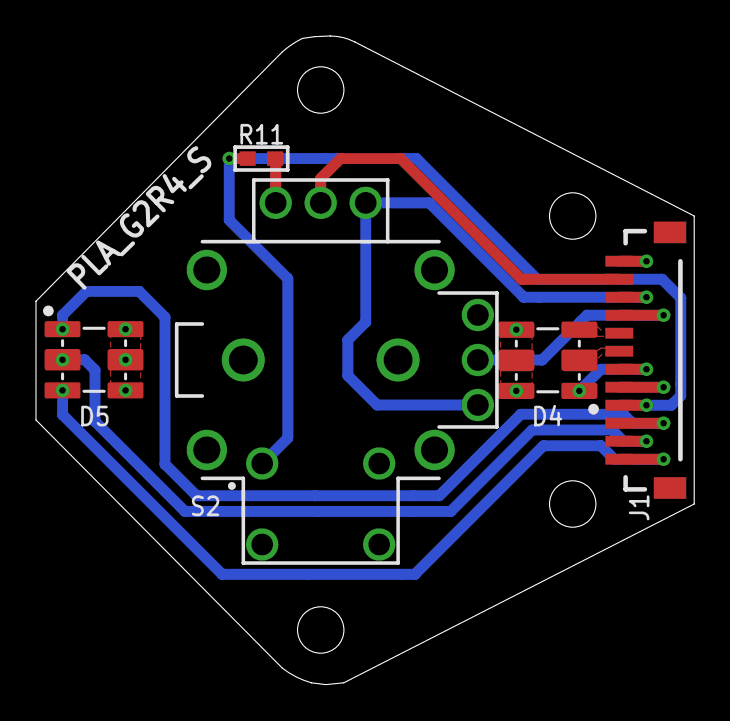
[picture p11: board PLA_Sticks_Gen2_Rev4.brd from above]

Board: 4 copper layers, 36.6 x 36.0 mm, 11 parts (0 on the bottom side), 12 nets.

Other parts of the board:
U$3: FAB_FRAME_ANSI-A
U$4: FAB_DOCFIELD_GENERIC
U$6, U$7, U$8, U$9: 101-NS

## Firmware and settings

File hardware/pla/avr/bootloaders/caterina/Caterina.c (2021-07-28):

/*
             LUFA Library
     Copyright (C) Dean Camera, 2011.

  dean [at] fourwalledcubicle [dot] com
           www.lufa-lib.org
*/

/*
  Copyright 2011  Dean Camera (dean [at] fourwalledcubicle [dot] com)

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
  The author disclaim all warranties with regard to this
  software, including all implied warranties of merchantability
  and fitness.  In no event shall the author be liable for any
  special, indirect or consequential damages or any damages
  whatsoever resulting from loss of use, data or profits, whether
  in an action of contract, negligence or other tortious action,
  arising out of or in connection with the use or performance of
  this software.
*/

/** \file
 *
 *  Main source file for the CDC class bootloader. This file contains the complete bootloader logic.
 */

#define  INCLUDE_FROM_CATERINA_C
#include "Caterina.h"

/** Contains the current baud rate and other settings of the first virtual serial port. This must be retained as some
 *  operating systems will not open the port unless the settings can be set successfully.
 */
static CDC_LineEncoding_t LineEncoding = { .BaudRateBPS = 0,
                                           .CharFormat  = CDC_LINEENCODING_OneStopBit,
                                           .ParityType  = CDC_PARITY_None,
                                           .DataBits    = 8                            };

/** Current address counter. This stores the current address of the FLASH or EEPROM as set by the host,
 *  and is used when reading or writing to the AVRs memory (either FLASH or EEPROM depending on the issued
 *  command.)
 */
static uint32_t CurrAddress;

// MAH 8/15/12- let's make this an 8-bit value instead of 16- that saves on memory because 16-bit addition and
//  comparison compiles to bulkier code. Note that this does *not* require a change to the Arduino core- we're 
//  just sort of ignoring the extra byte that the Arduino core puts at the next location.
//uint8_t bootKey = 0x77;
volatile uint8_t *const bootKeyPtr = (volatile uint8_t *)0x0800;

void StartSketch(void)
{
	cli();
	
	/* Relocate the interrupt vector table to the application section */
	MCUCR = (1 << IVCE);
	MCUCR = 0;

	/* jump to beginning of application space */
	__asm__ volatile("jmp 0x0000");
}

/** Main program entry point. This routine configures the hardware required by the bootloader, then continuously
 *  runs the bootloader processing routine until it times out or is instructed to exit.
 */
int main(void)
{
	*bootKeyPtr = 0;
	MCUSR = 0;

	wdt_disable();

	// Disable clock division 
	clock_prescale_set(clock_div_1);

	// Relocate the interrupt vector table to the bootloader section
	MCUCR = (1 << IVCE);
	MCUCR = (1 << IVSEL);
	
	CPU_PRESCALE(0); 

    // tcsullivan 7/22/21 - Setup joystick right button for staying in bootloader
    DDRE &= ~(1 << 6);
    PORTE |= (1 << 6);
	
    // Check if sketch is present
    bool sketchPresent = pgm_read_word(0) != 0xFFFF;
	
	/* Initialize USB Subsystem */
	USB_Init();

	/* Enable global interrupts so that the USB stack can function */
	sei();
	
    // Check joystick right button. If pressed, stay in the bootloader.
    if (!sketchPresent || (PINE & (1 << 6)) == 0) {
        while (1) {
		    CDC_Task();
		    USB_USBTask();
        }
    }

    // End bootloader USB and start the sketch
	USB_Detach();
	StartSketch();
}

/** Event handler for the USB_ConfigurationChanged event. This configures the device's endpoints ready
 *  to relay data to and from the attached USB host.
 */
void EVENT_USB_Device_ConfigurationChanged(void)
{
	/* Setup CDC Notification, Rx and Tx Endpoints */
	Endpoint_ConfigureEndpoint(CDC_NOTIFICATION_EPNUM, EP_TYPE_INTERRUPT,
	                           ENDPOINT_DIR_IN, CDC_NOTIFICATION_EPSIZE,
	                           ENDPOINT_BANK_SINGLE);

	Endpoint_ConfigureEndpoint(CDC_TX_EPNUM, EP_TYPE_BULK,
	                           ENDPOINT_DIR_IN, CDC_TXRX_EPSIZE,
	                           ENDPOINT_BANK_SINGLE);

	Endpoint_ConfigureEndpoint(CDC_RX_EPNUM, EP_TYPE_BULK,
	                           ENDPOINT_DIR_OUT, CDC_TXRX_EPSIZE,
	                           ENDPOINT_BANK_SINGLE);
}

/** Event handler for the USB_ControlRequest event. This is used to catch and process control requests sent to
 *  the device from the USB host before passing along unhandled control requests to the library for processing
 *  internally.
 */
void EVENT_USB_Device_ControlRequest(void)
{
	/* Ignore any requests that aren't directed to the CDC interface */
	if ((USB_ControlRequest.bmRequestType & (CONTROL_REQTYPE_TYPE | CONTROL_REQTYPE_RECIPIENT)) !=
	    (REQTYPE_CLASS | REQREC_INTERFACE))
	{
		return;
	}

	/* Process CDC specific control requests */
	switch (USB_ControlRequest.bRequest)
	{
		case CDC_REQ_GetLineEncoding:
			if (USB_ControlRequest.bmRequestType == (REQDIR_DEVICETOHOST | REQTYPE_CLASS | REQREC_INTERFACE))
			{
				Endpoint_ClearSETUP();

				/* Write the line coding data to the control endpoint */
				Endpoint_Write_Control_Stream_LE(&LineEncoding, sizeof(CDC_LineEncoding_t));
				Endpoint_ClearOUT();
			}

			break;
		case CDC_REQ_SetLineEncoding:
			if (USB_ControlRequest.bmRequestType == (REQDIR_HOSTTODEVICE | REQTYPE_CLASS | REQREC_INTERFACE))
			{
				Endpoint_ClearSETUP();

				/* Read the line coding data in from the host into the global struct */
				Endpoint_Read_Control_Stream_LE(&LineEncoding, sizeof(CDC_LineEncoding_t));
				Endpoint_ClearIN();
			}

			break;
	}
}

#if !defined(NO_BLOCK_SUPPORT)
/** Reads or writes a block of EEPROM or FLASH memory to or from the appropriate CDC data endpoint, depending
 *  on the AVR910 protocol command issued.
 *
 *  \param[in] Command  Single character AVR910 protocol command indicating what memory operation to perform
 */
static void ReadWriteMemoryBlock(const uint8_t Command)
{
	uint16_t BlockSize;
	char     MemoryType;

	bool     HighByte = false;
	uint8_t  LowByte  = 0;

	BlockSize  = (FetchNextCommandByte() << 8);
	BlockSize |=  FetchNextCommandByte();

	MemoryType =  FetchNextCommandByte();

	if ((MemoryType != 'E') && (MemoryType != 'F'))
	{
		/* Send error byte back to the host */
		WriteNextResponseByte('?');

		return;
	}

	/* Check if command is to read memory */
	if (Command == 'g')
	{		
		/* Re-enable RWW section */
		boot_rww_enable();

		while (BlockSize--)
		{
			if (MemoryType == 'F')
			{
				/* Read the next FLASH byte from the current FLASH page */
				#if (FLASHEND > 0xFFFF)
				WriteNextResponseByte(pgm_read_byte_far(CurrAddress | HighByte));
				#else
				WriteNextResponseByte(pgm_read_byte(CurrAddress | HighByte));
				#endif

				/* If both bytes in current word have been read, increment the address counter */
				if (HighByte)
				  CurrAddress += 2;

				HighByte = !HighByte;
			}
			else
			{
				/* Read the next EEPROM byte into the endpoint */
				WriteNextResponseByte(eeprom_read_byte((uint8_t*)(intptr_t)(CurrAddress >> 1)));

				/* Increment the address counter after use */
				CurrAddress += 2;
			}
		}
	}
	else
	{
		uint32_t PageStartAddress = CurrAddress;

		if (MemoryType == 'F')
		{
			boot_page_erase(PageStartAddress);
			boot_spm_busy_wait();
		}

		while (BlockSize--)
		{
			if (MemoryType == 'F')
			{
				/* If both bytes in current word have been written, increment the address counter */
				if (HighByte)
				{
					/* Write the next FLASH word to the current FLASH page */
					boot_page_fill(CurrAddress, ((FetchNextCommandByte() << 8) | LowByte));

					/* Increment the address counter after use */
					CurrAddress += 2;
				}
				else
				{
					LowByte = FetchNextCommandByte();
				}
				
				HighByte = !HighByte;
			}
			else
			{
				/* Write the next EEPROM byte from the endpoint */
				eeprom_write_byte((uint8_t*)((intptr_t)(CurrAddress >> 1)), FetchNextCommandByte());

				/* Increment the address counter after use */
				CurrAddress += 2;
			}
		}

		/* If in FLASH programming mode, commit the page after writing */
		if (MemoryType == 'F')
		{
			/* Commit the flash page to memory */
			boot_page_write(PageStartAddress);

			/* Wait until write operation has completed */
			boot_spm_busy_wait();
		}

		/* Send response byte back to the host */
		WriteNextResponseByte('\r');
	}
}
#endif

/** Retrieves the next byte from the host in the CDC data OUT endpoint, and clears the endpoint bank if needed
 *  to allow reception of the next data packet from the host.
 *
 *  \return Next received byte from the host in the CDC data OUT endpoint
 */
static uint8_t FetchNextCommandByte(void)
{
	/* Select the OUT endpoint so that the next data byte can be read */
	Endpoint_SelectEndpoint(CDC_RX_EPNUM);

	/* If OUT endpoint empty, clear it and wait for the next packet from the host */
	while (!(Endpoint_IsReadWriteAllowed()))
	{
		Endpoint_ClearOUT();

		while (!(Endpoint_IsOUTReceived()))
		{
			if (USB_DeviceState == DEVICE_STATE_Unattached)
			  return 0;
		}
	}

	/* Fetch the next byte from the OUT endpoint */
	return Endpoint_Read_8();
}

/** Writes the next response byte to the CDC data IN endpoint, and sends the endpoint back if needed to free up the
 *  bank when full ready for the next byte in the packet to the host.
 *
 *  \param[in] Response  Next response byte to send to the host
 */
static void WriteNextResponseByte(const uint8_t Response)
{
	/* Select the IN endpoint so that the next data byte can be written */
	Endpoint_SelectEndpoint(CDC_TX_EPNUM);

	/* If IN endpoint full, clear it and wait until ready for the next packet to the host */
	if (!(Endpoint_IsReadWriteAllowed()))
	{
		Endpoint_ClearIN();

		while (!(Endpoint_IsINReady()))
		{
			if (USB_DeviceState == DEVICE_STATE_Unattached)
			  return;
		}
	}

	/* Write the next byte to the IN endpoint */
	Endpoint_Write_8(Response);
}

#define STK_OK              0x10
#define STK_INSYNC          0x14  // ' '
#define CRC_EOP             0x20  // 'SPACE'
#define STK_GET_SYNC        0x30  // '0'

#define STK_GET_PARAMETER   0x41  // 'A'
#define STK_SET_DEVICE      0x42  // 'B'
#define STK_SET_DEVICE_EXT  0x45  // 'E'
#define STK_LOAD_ADDRESS    0x55  // 'U'
#define STK_UNIVERSAL       0x56  // 'V'
#define STK_PROG_PAGE       0x64  // 'd'
#define STK_READ_PAGE       0x74  // 't'
#define STK_READ_SIGN       0x75  // 'u'

/** Task to read in AVR910 commands from the CDC data OUT endpoint, process them, perform the required actions
 *  and send the appropriate response back to the host.
 */
void CDC_Task(void)
{
	/* Select the OUT endpoint */
	Endpoint_SelectEndpoint(CDC_RX_EPNUM);

	/* Check if endpoint has a command in it sent from the host */
	if (!(Endpoint_IsOUTReceived()))
	  return;
	  
	/* Read in the bootloader command (first byte sent from host) */
	uint8_t Command = FetchNextCommandByte();

	if (Command == 'E')
	{
		/* Re-enable RWW section - must be done here in case 
		 * user has disabled verification on upload.  */
		boot_rww_enable_safe();		

		// Send confirmation byte back to the host 
		WriteNextResponseByte('\r');
	}
	else if (Command == 'T')
	{
		FetchNextCommandByte();

		// Send confirmation byte back to the host 
		WriteNextResponseByte('\r');
	}
	else if ((Command == 'L') || (Command == 'P'))
	{
		// Send confirmation byte back to the host 
		WriteNextResponseByte('\r');
	}
	else if (Command == 't')
	{
		// Return ATMEGA128 part code - this is only to allow AVRProg to use the bootloader 
		WriteNextResponseByte(0x44);
		WriteNextResponseByte(0x00);
	}
	else if (Command == 'a')
	{
		// Indicate auto-address increment is supported 
		WriteNextResponseByte('Y');
	}
	else if (Command == 'A')
	{
		// Set the current address to that given by the host 
		CurrAddress   = (FetchNextCommandByte() << 9);
		CurrAddress  |= (FetchNextCommandByte() << 1);

		// Send confirmation byte back to the host 
		WriteNextResponseByte('\r');
	}
	else if (Command == 'p')
	{
		// Indicate serial programmer back to the host 
		WriteNextResponseByte('S');
	}
	else if (Command == 'S')
	{
		// Write the 7-byte software identifier to the endpoint 
		for (uint8_t CurrByte = 0; CurrByte < 7; CurrByte++)
		  WriteNextResponseByte(SOFTWARE_IDENTIFIER[CurrByte]);
	}
	else if (Command == 'V')
	{
		WriteNextResponseByte('0' + BOOTLOADER_VERSION_MAJOR);
		WriteNextResponseByte('0' + BOOTLOADER_VERSION_MINOR);
	}
	else if (Command == 's')
	{
		WriteNextResponseByte(AVR_SIGNATURE_3);
		WriteNextResponseByte(AVR_SIGNATURE_2);
		WriteNextResponseByte(AVR_SIGNATURE_1);
	}
	else if (Command == 'e')
	{
		// Clear the application section of flash 
		for (uint32_t CurrFlashAddress = 0; CurrFlashAddress < BOOT_START_ADDR; CurrFlashAddress += SPM_PAGESIZE)
		{
			boot_page_erase(CurrFlashAddress);
			boot_spm_busy_wait();
			boot_page_write(CurrFlashAddress);
			boot_spm_busy_wait();
		}

		// Send confirmation byte back to the host 
		WriteNextResponseByte('\r');
	}
	#if !defined(NO_LOCK_BYTE_WRITE_SUPPORT)
	else if (Command == 'l')
	{
		// Set the lock bits to those given by the host 
		boot_lock_bits_set(FetchNextCommandByte());

		// Send confirmation byte back to the host 
		WriteNextResponseByte('\r');
	}
	#endif
	else if (Command == 'r')
	{
		WriteNextResponseByte(boot_lock_fuse_bits_get(GET_LOCK_BITS));
	}
	else if (Command == 'F')
	{
		WriteNextResponseByte(boot_lock_fuse_bits_get(GET_LOW_FUSE_BITS));
	}
	else if (Command == 'N')
	{
		WriteNextResponseByte(boot_lock_fuse_bits_get(GET_HIGH_FUSE_BITS));
	}
	else if (Command == 'Q')
	{
		WriteNextResponseByte(boot_lock_fuse_bits_get(GET_EXTENDED_FUSE_BITS));
	}
	#if !defined(NO_BLOCK_SUPPORT)
	else if (Command == 'b')
	{
		WriteNextResponseByte('Y');

		// Send block size to the host 
		WriteNextResponseByte(SPM_PAGESIZE >> 8);
		WriteNextResponseByte(SPM_PAGESIZE & 0xFF);
	}
	else if ((Command == 'B') || (Command == 'g'))
	{
		// Delegate the block write/read to a separate function for clarity 
		ReadWriteMemoryBlock(Command);
	}
	#endif
	#if !defined(NO_FLASH_BYTE_SUPPORT)
	else if (Command == 'C')
	{
		// Write the high byte to the current flash page
		boot_page_fill(CurrAddress, FetchNextCommandByte());

		// Send confirmation byte back to the host 
		WriteNextResponseByte('\r');
	}
	else if (Command == 'c')
	{
		// Write the low byte to the current flash page 
		boot_page_fill(CurrAddress | 0x01, FetchNextCommandByte());

		// Increment the address 
		CurrAddress += 2;

		// Send confirmation byte back to the host 
		WriteNextResponseByte('\r');
	}
	else if (Command == 'm')
	{
		// Commit the flash page to memory
		boot_page_write(CurrAddress);

		// Wait until write operation has completed 
		boot_spm_busy_wait();

		// Send confirmation byte back to the host 
		WriteNextResponseByte('\r');
	}
	else if (Command == 'R')
	{
		#if (FLASHEND > 0xFFFF)
		uint16_t ProgramWord = pgm_read_word_far(CurrAddress);
		#else
		uint16_t ProgramWord = pgm_read_word(CurrAddress);
		#endif

		WriteNextResponseByte(ProgramWord >> 8);
		WriteNextResponseByte(ProgramWord & 0xFF);
	}
	#endif
	#if !defined(NO_EEPROM_BYTE_SUPPORT)
	else if (Command == 'D')
	{
		// Read the byte from the endpoint and write it to the EEPROM 
		eeprom_write_byte((uint8_t*)((intptr_t)(CurrAddress >> 1)), FetchNextCommandByte());

		// Increment the address after use
		CurrAddress += 2;

		// Send confirmation byte back to the host 
		WriteNextResponseByte('\r');
	}
	else if (Command == 'd')
	{
		// Read the EEPROM byte and write it to the endpoint 
		WriteNextResponseByte(eeprom_read_byte((uint8_t*)((intptr_t)(CurrAddress >> 1))));

		// Increment the address after use 
		CurrAddress += 2;
	}
	#endif
	else if (Command != 27)
	{
		// Unknown (non-sync) command, return fail code 
		WriteNextResponseByte('?');
	}
	

	/* Select the IN endpoint */
	Endpoint_SelectEndpoint(CDC_TX_EPNUM);

	/* Remember if the endpoint is completely full before clearing it */
	bool IsEndpointFull = !(Endpoint_IsReadWriteAllowed());

	/* Send the endpoint data to the host */
	Endpoint_ClearIN();

	/* If a full endpoint's worth of data was sent, we need to send an empty packet afterwards to signal end of transfer */
	if (IsEndpointFull)
	{
		while (!(Endpoint_IsINReady()))
		{
			if (USB_DeviceState == DEVICE_STATE_Unattached)
			  return;
		}

		Endpoint_ClearIN();
	}

	/* Wait until the data has been sent to the host */
	while (!(Endpoint_IsINReady()))
	{
		if (USB_DeviceState == DEVICE_STATE_Unattached)
		  return;
	}

	/* Select the OUT endpoint */
	Endpoint_SelectEndpoint(CDC_RX_EPNUM);

	/* Acknowledge the command from the host */
	Endpoint_ClearOUT();
}

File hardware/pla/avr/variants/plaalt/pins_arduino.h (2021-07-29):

/*
  pins_arduino.h - Pin definition functions for Arduino
  Part of Arduino - http://www.arduino.cc/

  Copyright (c) 2007 David A. Mellis

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
  $Id: wiring.h 249 2007-02-03 16:52:51Z mellis $
*/

#ifndef Pins_Arduino_h
#define Pins_Arduino_h

#include <avr/pgmspace.h>

// Workaround for wrong definitions in "iom32u4.h".
// This should be fixed in the AVR toolchain.
#undef UHCON
#undef UHINT
#undef UHIEN
#undef UHADDR
#undef UHFNUM
#undef UHFNUML
#undef UHFNUMH
#undef UHFLEN
#undef UPINRQX
#undef UPINTX
#undef UPNUM
#undef UPRST
#undef UPCONX
#undef UPCFG0X
#undef UPCFG1X
#undef UPSTAX
#undef UPCFG2X
#undef UPIENX
#undef UPDATX
#undef TCCR2A
#undef WGM20
#undef WGM21
#undef COM2B0
#undef COM2B1
#undef COM2A0
#undef COM2A1
#undef TCCR2B
#undef CS20
#undef CS21
#undef CS22
#undef WGM22
#undef FOC2B
#undef FOC2A
#undef TCNT2
#undef TCNT2_0
#undef TCNT2_1
#undef TCNT2_2
#undef TCNT2_3
#undef TCNT2_4
#undef TCNT2_5
#undef TCNT2_6
#undef TCNT2_7
#undef OCR2A
#undef OCR2_0
#undef OCR2_1
#undef OCR2_2
#undef OCR2_3
#undef OCR2_4
#undef OCR2_5
#undef OCR2_6
#undef OCR2_7
#undef OCR2B
#undef OCR2_0
#undef OCR2_1
#undef OCR2_2
#undef OCR2_3
#undef OCR2_4
#undef OCR2_5
#undef OCR2_6
#undef OCR2_7

#define NUM_DIGITAL_PINS  31
#define NUM_ANALOG_INPUTS 12

#define TX_RX_LED_INIT  DDRD |= (1<<5), DDRB |= (1<<0)
#define TXLED0          PORTD |= (1<<5)
#define TXLED1          PORTD &= ~(1<<5)
#define RXLED0          PORTB |= (1<<0)
#define RXLED1          PORTB &= ~(1<<0)

static const uint8_t SDA = 2;
static const uint8_t SCL = 3;
#define LED_BUILTIN 13
#define LED_BUILTIN_RX 17					
#define LED_BUILTIN_TX 30

// Map SPI port to 'new' pins D14..D17
static const uint8_t SS   = 17;
static const uint8_t MOSI = 16;
static const uint8_t MISO = 14;
static const uint8_t SCK  = 15;

// Mapping of analog pins as digital I/O
// A6-A11 share with digital pins
static const uint8_t A0 = 18;
static const uint8_t A1 = 19;
static const uint8_t A2 = 20;
static const uint8_t A3 = 21;
static const uint8_t A4 = 22;
static const uint8_t A5 = 23;
static const uint8_t A6 = 24;   // D4
static const uint8_t A7 = 25;   // D6
static const uint8_t A8 = 26;   // D8
static const uint8_t A9 = 27;   // D9
static const uint8_t A10 = 28;  // D10
static const uint8_t A11 = 29;  // D12

#define digitalPinToPCICR(p)    ((((p) >= 8 && (p) <= 11) || ((p) >= 14 && (p) <= 17) || ((p) >= A8 && (p) <= A10)) ? (&PCICR) : ((uint8_t *)0))
#define digitalPinToPCICRbit(p) 0
#define digitalPinToPCMSK(p)    ((((p) >= 8 && (p) <= 11) || ((p) >= 14 && (p) <= 17) || ((p) >= A8 && (p) <= A10)) ? (&PCMSK0) : ((uint8_t *)0))
#define digitalPinToPCMSKbit(p) ( ((p) >= 8 && (p) <= 11) ? (p) - 4 : ((p) == 14 ? 3 : ((p) == 15 ? 1 : ((p) == 16 ? 2 : ((p) == 17 ? 0 : (p - A8 + 4))))))

//  __AVR_ATmega32U4__ has an unusual mapping of pins to channels
extern const uint8_t PROGMEM analog_pin_to_channel_PGM[];
#define analogPinToChannel(P)  ( pgm_read_byte( analog_pin_to_channel_PGM + (P) ) )

#define digitalPinToInterrupt(p) ((p) == 0 ? 2 : ((p) == 1 ? 3 : ((p) == 2 ? 1 : ((p) == 3 ? 0 : ((p) == 7 ? 4 : NOT_AN_INTERRUPT)))))

#ifdef ARDUINO_MAIN

// On the Arduino board, digital pins are also used
// for the analog output (software PWM).  Analog input
// pins are a separate set.

// ATMEL ATMEGA32U4 / ARDUINO LEONARDO
//
// D0               PD2                 RXD1/INT2
// D1               PD3                 TXD1/INT3
// D2               PD1     SDA         SDA/INT1
// D3#              PD0     PWM8/SCL    OC0B/SCL/INT0
// D4       A6      PD4                 ADC8
// D5#              PC6     ???         OC3A/#OC4A
// D6#      A7      PD7     FastPWM     #OC4D/ADC10
// D7               PE6                 INT6/AIN0
//
// D8       A8      PB4                 ADC11/PCINT4
// D9#      A9      PB5     PWM16       OC1A/#OC4B/ADC12/PCINT5
// D10#     A10     PB6     PWM16       OC1B/0c4B/ADC13/PCINT6
// D11#             PB7     PWM8/16     0C0A/OC1C/#RTS/PCINT7
// D12      A11     PD6                 T1/#OC4D/ADC9
// D13#             PC7     PWM10       CLK0/OC4A
//
// A0       D18     PF7                 ADC7
// A1       D19     PF6                 ADC6
// A2       D20     PF5                 ADC5
// A3       D21     PF4                 ADC4
// A4       D22     PF1                 ADC1
// A5       D23     PF0                 ADC0
//
// New pins D14..D17 to map SPI port to digital pins
//
// MISO     D14     PB3                 MISO,PCINT3
// SCK      D15     PB1                 SCK,PCINT1
// MOSI     D16     PB2                 MOSI,PCINT2
// SS       D17     PB0                 RXLED,SS/PCINT0
//
// Connected LEDs on board for TX and RX
// TXLED    D30     PD5                 XCK1
// RXLED    D17     PB0
// HWB              PE2                 HWB
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

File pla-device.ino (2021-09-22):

/**
 * pla-device.ino: Firmware code for the PLA ALT Avatar Motion Controller.
 * Copyright (C) 2021  PLA LABS
 *
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
 * You should have received a copy of the GNU General Public License
 * along with this program.  If not, see <https://www.gnu.org/licenses/>.
 */

#include "Joystick.h"
#include "lp55231.h"
#include "SparkFunSX1509.h"
#include "util/sx1509_registers.h"

#include <EEPROM.h>

// Uncomment to swap loop() for a serial dump of inputs.
//#define DEBUG

// Default controller LED color.
//#define COLOR_DEFAULT (0x03F7FF)
#define COLOR_DEFAULT (0x001819)

// Number of milliseconds between updating controller state.
#define JOY_TIMEDELTA (10)

// Number of times to poll joystick zero position for calibration.
#define JOY_CALIB_COUNT (8)

// Joystick analog range parameters.
#define JOY_CENTER    (512)
#define JOY_RANGE     (250)
#define JOY_RANGELOW  (JOY_CENTER - JOY_RANGE)
#define JOY_RANGEHIGH (JOY_CENTER + JOY_RANGE)

// Wheel analog range parameters.
#define WHL_OVERSAMPLE_COUNT (10)
#define WHL_RANGE     (76 * WHL_OVERSAMPLE_COUNT)
#define WHL_CENTER    ((1023 * WHL_OVERSAMPLE_COUNT) / 2)
#define WHL_RANGELOW  (WHL_CENTER - WHL_RANGE)
#define WHL_RANGEHIGH (WHL_CENTER + WHL_RANGE)
#define WHL_THRESHOLD (WHL_RANGE * 21 / 100)

static Joystick_ joy (JOYSTICK_DEFAULT_REPORT_ID, JOYSTICK_TYPE_JOYSTICK,
    11, 0,                // Button count, hat switch count
    true, true, true,     // X/Y/Z axis
    true, true, true,     // Rx/Ry/Rz axis
    false, true,          // Rudder, throttle (used for wheel)
    false, false, false); // Accelerator, brake, steering

/**
 * @class PgButtons
 * @brief Handles and provides control over the PG buttons and LEDs.
 */
class PgButtons {
private:
    static SX1509 io;

    // Maps PG number (0-7) to its LED pin.
    static const int leds[8];
    // Maps PG number to its button pin.
    static const int buttons[8];

    // If true, light LED corresponding to active PG key.
    static bool trackingPG;
    // Tracks last pressed PG key.
    static unsigned int lastPressed;

public:
    /**
     * Prepares the PG buttons and LEDs for use.
     */
    static void begin(void) {
        io.begin(0x3E);

        for (int i = 0; i < 8; i++)
            io.pinMode(buttons[i], INPUT_PULLUP);

        if (trackingPG) {
            for (int i = 0; i < 8; i++) {
                 io.pinMode(leds[i], OUTPUT);
                setLed(i, false);
            }
            setLed(lastPressed, true);
        } else {
            // Have LEDs breathe if not in use.
            io.clock(INTERNAL_CLOCK_2MHZ, 3);
            io.writeByte(REG_OPEN_DRAIN_A, 0xF0);
            io.writeByte(REG_OPEN_DRAIN_B, 0xF0);
            for (int i = 0; i < 8; i++) {
                io.ledDriverInit(leds[i]);
                io.breathe(leds[i], 750, 250, 2000, 2000);
            }
        }
    }

    /**
     * Enables or disables lighting LEDs according to the current PG.
     * @param enable True to enable LEDs
     */
    static void trackPG(bool enable) {
        trackingPG = enable;
        io.reset(true);
        begin();
    }

    /**
     * Reads the state of the given button.
     * @param n Index of the button, 0-7
     * @return True if the button is in a pressed state
     */
    static bool read(unsigned int n) {
        if (n < 8) {
            bool state = !io.digitalRead(buttons[n]);
            // Update LEDs if a new PG button is pressed
            if (trackingPG && lastPressed != n && state) {
                setLed(lastPressed, false);
                setLed(n, true);
                lastPressed = n;
            }
            return state;
        } else {
            return false;
        }
    }

    static void selectPG(unsigned int n) {
        if (n < 8) {
            setLed(lastPressed, false);
            setLed(n, true);
            lastPressed = n;
        }
    }

    /**
     * Runs an LED sequence, so that the user can check for faulty LEDs.
     */
    static void testLeds(void) {
        for (int i = 0; i < 5; i++) {
            for (int j = 0; j < 8; j++)
                setLed(j, true);
            delay(50);
            for (int j = 0; j < 8; j++)
                setLed(j, false);
            delay(50);
        }
    }

    static int getPg() {
      return lastPressed;
    }

private:
    static void setLed(unsigned int n, bool state) {
        if (n < 8)
            io.digitalWrite(leds[n], !state);
    }
};

/**
 * @class RgbLed
 * @brief Handles and controls the RGB LEDs.
 */
class RgbLed {
private:
    // Object for controlling the RGB LED driver chips.
    static Lp55231 rgb[2];

    // Defines the RGB channels for each LED connected to the LED chip.
    static const char channel[9];

public:
    /**
     * Prepares the RGB LEDs for use.
     */
    static void begin(void) {
        for (int i = 0; i < 2; i++) {
            rgb[i].Begin();
            rgb[i].Enable();
        }
    }

    /**
     * Sets the given LED on the LED driver to the desired RGB value.
     * @param n the LED to set, 0-5
     * @param rgb24 the 24-bit RGB value to write
     */
    static void set(unsigned int n, unsigned long rgb24) {
        int index = 0;
        if (n > 2) {
            index = 1;
            n -= 3;
        }

        for (int i = 0; i < 3; i++) {
            rgb[index].SetChannelPWM(channel[n * 3 + i],
                (rgb24 >> (8 * (2 - i))) & 0xFF);
        }
    }

    /**
     * Sets all LEDs to the given color.
     * @param rgb24 The 24-bit RGB value to write
     */
    static void setAll(unsigned long rgb24) {
        for (unsigned int i = 0; i < 6; i++)
            set(i, rgb24);
    }
};

/**
 * Calibration offsets for all of the joysticks and wheel.
 * Array index corresponds to the analog pin index.
 */
static int joyCalibrations[7] = {
    0, 0, 0, 0, 0, 0, 0
};
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

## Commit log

2019-06-13 better analog steering
2019-08-06 fixed joystick/wheel ranges
2021-01-08 fix test mode color overflow; fix indentation
    [pla-device.ino]
2021-06-10 fix for prod. proto.; improve debug
    [pla-device.ino]
2021-06-17 wheel calibration; idle sleep; faster update rate
2021-07-28 minimized bootloader; joystick calibration
2021-08-13 query pg; fix id response
    [pla-device.ino]
2021-08-19 color fix; send joy state once per loop
    [pla-device.ino]
2021-08-19 improve wheel accuracy
2021-08-20 wheel: improved oversampling/deadzone
2021-08-23 Remove wheel averaging
2021-08-25 upload eagle files
    [PLA_Controller_combined_Gen2_Rev4.brd, PLA_Controller_combined_Gen2_Rev4.sch, PLA_Controller_ring_Gen2_Rev2.brd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]

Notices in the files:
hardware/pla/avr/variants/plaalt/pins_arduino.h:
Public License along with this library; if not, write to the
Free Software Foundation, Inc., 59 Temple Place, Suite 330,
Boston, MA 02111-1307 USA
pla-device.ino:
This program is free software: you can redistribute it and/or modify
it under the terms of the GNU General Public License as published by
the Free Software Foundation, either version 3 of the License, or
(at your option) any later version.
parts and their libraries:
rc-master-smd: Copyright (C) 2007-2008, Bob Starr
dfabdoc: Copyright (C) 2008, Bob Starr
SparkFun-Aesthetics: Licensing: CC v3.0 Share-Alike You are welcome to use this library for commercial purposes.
